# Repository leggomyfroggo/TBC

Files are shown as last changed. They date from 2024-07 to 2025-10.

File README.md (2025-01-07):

# TBC

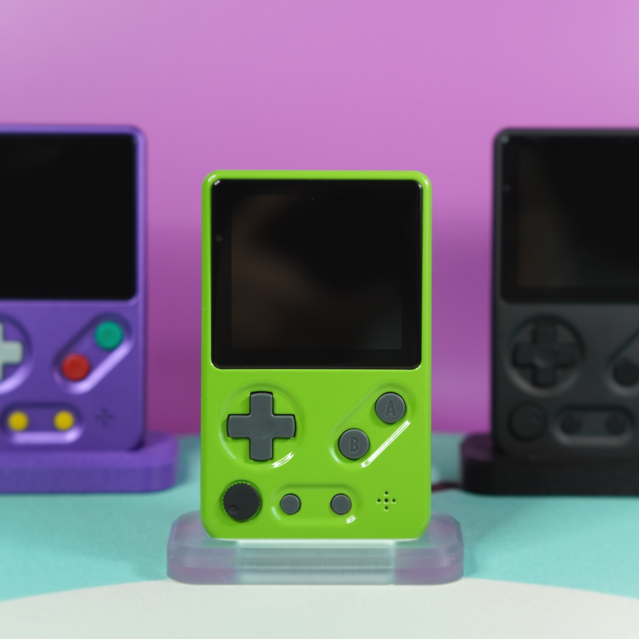
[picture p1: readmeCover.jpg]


The Tad Boy color is an answer to the question: how small can you make a Game Boy Color while still accepting original cartridges? That's it, that's all you get.

# Attribution
Before getting to the build, it's important to provide attribution to the other project(s) that have in part gone into the Tad Boy Color.
- **[Gekkio/gekkio-kicad-libs](https://github.com/Gekkio/gekkio-kicad-libs)**: The TBC incorporates several of Gekkio's excellent kicad symbols and footprints, including for the CPU, RAM(modified), link port, and cartridge connector. Huge thanks to Gekkio for making these available for others to use!
- Cody Wick for the incredible name suggestion, holy shit

# License
The Tad Boy Color and associated files are licensed under a CC BY-NC-ND 4.0 license. In short, this means:
- If you share the files, you must provide attribution.
- Commercial uses are not allowed without permission, i.e. production and sale of Tad Boy Colors or parts for profit is not allowed.
- You are free to modify these files for your own private use, but you are not allowed to distribute modified files.
Full license is linked at the bottom of this document.

# Disclaimer/Warning/For the love of God, read this
The Tad Boy is not an easy project, nor is it a professional product, and as such there are some things to keep in mind as you consider building one.

Assembly of the Tad Boy requires intermediate-advanced skills in soldering and electronics tinkering, including:
- Desoldering/soldering of large ICs
- Desoldering of through hole parts
- Soldering of small surface mount components, down to 0402
- Soldering of leadless ICs, for example the TPS61202
- Proficiency with a multimeter for troubleshooting and validation

This is in no way a project for beginners, and if you don't have experience with the above, I highly recommend starting smaller -- solder practice kits are cheap and easily available.

Along with needing the requisite skills, there is a very real possibility that you will irreparably damage either your donor Game Boy Color, or the resulting Tad Boy. Even the most skilled among us make mistakes, but it's important to keep in mind your own limits to avoid heartache and sorrow.

I am in no way a professional electrical engineer. All of my skills are self taught, or learned from other members of the modding community. While I have taken common sense measures to ensure that the Frog Boy is functional and safe, I can not guarantee that each and every decision made is correct. Build at your own discretion.

In summary, build at your own risk. I am not liable for any damage or injury caused by your insatiable need to build a Game Boy named after a baby amphibian.

# Navigating this Repo
- The files you will need to produce the Tad Boy Color parts are located in the `production_files` folder.
  - Files for each major piece are located in their own subfolders.
  - In general, production files are named according to the name of the part plus a 6 digit date code indicating the date of release.
    - PCB versions are the exception to this rule, and are labeled according to the board revision, e.g. X5, 01, 02, etc
  - Production files for old parts are located in those parts' respective `archive` folders.
  - The latest versions of each part will be guaranteed to work with one another. I only recommend downloading archived versions if you really know what you're doing.
- An interactive BOM is available in the `ibom` folder. iBOMs for different PCB revisions are in their own subfolders. Select the iBOM version that matches your PCB.

# Bill of Materials(BOM)
Below is the breakdown of all materials you will need to build a Tad Boy Color.

## Build Components
- **PCB:** The Tad Boy Color uses a fully custom PCB designed to fit within the custom shell while still using many of the original GBC components. The following board parameters are **required** or highly recommended, all other paremeters(color, etc) are up to you:
  - **Layers:** 4-layer
  - **Thickness:** 1mm
  - **Surface finish(recommended):** ENIG. HASL will probably be okay, but may not play well with the speaker contacts over time.
  - [**Order from PCBWay**](https://www.pcbway.com/project/shareproject/Tad_Boy_Color_876e4f73.html)
- **LCD Adapter Flex:** The shape of the board and LCD connector used on the main PCB requires the use of a custom flex cable to connect the TBC to the screen kit. The following parameters are **required**:
  - **Layers:** 2-layer
  - **Thickness:** 0.1mm or 0.11mm FFC
  - **Stiffener:** 0.2mm PI stiffener on edge connectors for total 0.3mm thickness. Have your chosen fab refer to the stiffener instructions on the "User Comments" layer
  - [**Order from PCBWay**](https://www.pcbway.com/project/shareproject/Tad_Boy_Color_LCD_Adapter_Flex_44b0462a.html)
- **Shell:** The shell for the Tad Boy Color is a fully custom design, designed specifically for CNC machining -- resin 3D printing should work, but is untested. Tested and verified materials are below, but all orders are at your own risk:
  - Verified CNC materials: Aluminum, polycarbonate, stainless steel
  - [**Order from PCBWay**](https://www.pcbway.com/project/shareproject/Tad_Boy_Color_876e4f73.html)
- **Volume Wheel:** The volume wheel is another custom piece, and is intended to be CNC machined. Resin printing will probably work, but is untested.
  - 081124 version can fit a 8mm(OD)x5mm(ID)x0.5mm PTFE coated nylon washer to reduce friction between wheel and shell.
  - [**Order from PCBWay**](https://www.pcbway.com/project/shareproject/Tad_Boy_Color_876e4f73.html)
- **Cartridge Shield:** Custom piece that fits behind the cartridge, allowing for a large enough opening in the metal shell to machine.
  - Verified 3D printing materials: FDM PLA, SLS nylon, MJF nylon
  - Verified CNC materials: Aluminum
  - [**Order from PCBWay**](https://www.pcbway.com/project/shareproject/Tad_Boy_Color_876e4f73.html)
- **Light pipe:** An optional light pipe can be added for the indicator LEDs to better diffuse them.
  - Verified 3D printing materials: FDM clear PLA, SLA clear resin
  - [**Order from PCBWay**](https://www.pcbway.com/project/shareproject/Tad_Boy_Color_876e4f73.html)
- **Screws:** The shell is designed to be put together using 7 x M2 3mm machine screws with flat tops. Options:
  - **450pcs M2 M2.5 M3 Screw Kit:** [From Amazon](https://www.amazon.com/gp/product/B07TDHZJLL/)
- **Buttons:** The Tad Boy Color uses buttons from the Game Boy Advance SP, either OEM or aftermarket. You will need a complete set, including the brightness button which is repurposed here as the power button. Some suggested buttons:
  - **FunnyPlaying:** [From RGRS](https://retrogamerepairshop.com/collections/gba-sp-buttons/products/funnyplaying-game-boy-advance-sp-buttons)
  - **RetroCNC(membrane version):** [From RGRS](https://retrogamerepairshop.com/collections/gba-sp-buttons/products/new-game-boy-sp-metal-buttons-by-retrocnc)
- **Membranes:** Similarly, the membranes used are also from the Game Boy Advance SP. Some suggested membranes:
  - **FunnyPlaying:** [From RGRS](https://retrogamerepairshop.com/collections/gba-sp-buttons/products/funnyplaying-game-boy-advance-sp-silicone-pads)
- **Screen:** This project is designed exclusively for the CGS 2.45" LCD kit for the Game Boy Color.
  - [Order from RGRS](https://retrogamerepairshop.com/collections/gbc-displays/products/game-boy-color-2-45-drop-in-backlight-lcd-kit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)
  - [Order from AliExpress](https://www.aliexpress.us/item/3256803777135552.html)
- **Screen Lens:** The Tad Boy color makes use of a custom designed glass screen lens. Suggested suppliers:
  - [**Order from FroggoCustoms**](https://froggocustoms.com/products/tad-boy-color-base-kit) - lens coming separately soon
  - Alibaba, requires obtaining quote with technical drawings
- **Battery:** The Tad Boy Color is designed to make use of aftermarket Joy Con batteries with minimal effort. The outer shroud/casing must be removed to fit properly. OEM batteries likely won't fit.

  NOTE: LiPo batteries can be dangerous if mishandled. NEVER use unprotected cells.

## Shell Ordering Notes
### CNC Machining
- When ordering the front shell, make sure you check the box indicating that you need tapped threads.
- For both front and back shells, be sure to include the technical drawings, and select 0.1mm as the tightest tolerance.

## PCB Components
- **Harvested GBC Parts:** You will need a donor GBC of revision CPU-05 or earlier -- CPU-06 revisions will NOT work -- that retains the following components in working order:
  - CPU
  - RAM
  - Link port(also available new: [AliExpress](https://www.aliexpress.us/item/3256803930669143.html))
- **New parts:** The full BOM for the Tad Boy Color be found in the repo, `bom.xlsx`. All non-Game Boy parts can be found in the shared Mouser cart below, and for that reason is the preferred vendor. Other parts can be obtained at the suggested links.
  - Non-Game Boy components(NOTE: These carts do not contain LEDs. Pick 3 x 0603 LEDs in whatever colors you want for the indicators):
    - [Mouser Shared Project](https://www.mouser.com/ProjectManager/ProjectDetail.aspx?AccessID=6273a53e17)
    - [DigiKey Shared Project](https://www.digikey.com/en/mylists/list/A9QP98UG8B) - NOTE: DigiKey does not stock the crystal or volume potentiometer. Order from Mouser if you can.
  - Game Boy Advance SP cartridge slot: [AliExpress](https://www.aliexpress.us/item/3256802533466823.html)
 
# Recommended Assembly Procedure
At this point, if you feel confident in your skills you can proceed with the complete build from PCB to final unit -- assembly after building the PCB is relatively straightforward.

However, I've devised an assembly strategy after assembling a few units that will allow you to check your work along the way, and I highly recommend that you follow along.

Unless otherwise noted, you should install all highlighted parts in a given step, and then proceed to the corresponding "Testing" section.

## PCB Assembly
### 1. Tactile switches
While this step can be done at any point of your choosing, I recommend doing it first for two reasons:
1. When using a hot plate to install the tactile switches, it's much easier to do so when the PCB is otherwise empty, and
2. Installing them early lets you better test in later stages.

| Front Parts | Back Parts |
| --- | --- |
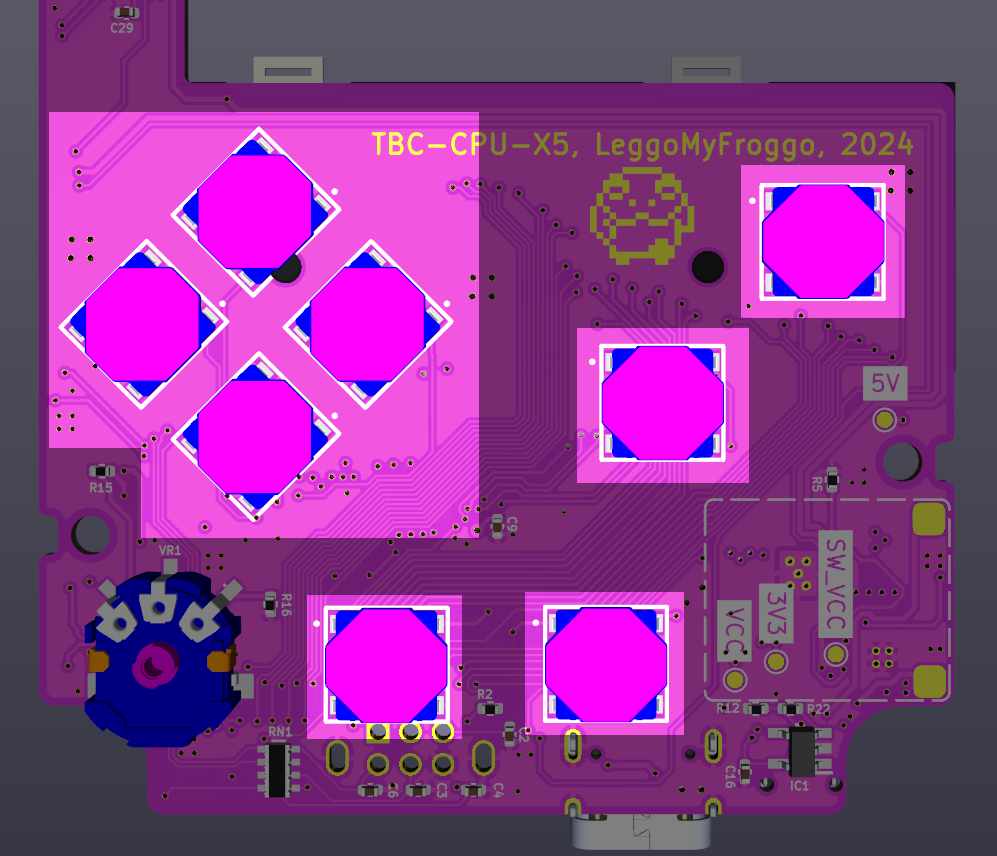
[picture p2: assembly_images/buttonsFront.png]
|  | N/A  |

### 2. Power
| Front Parts | Back Parts |
| --- | --- |
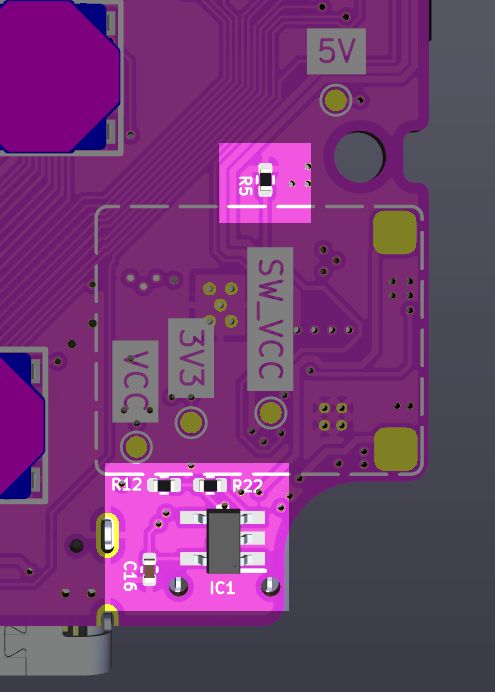
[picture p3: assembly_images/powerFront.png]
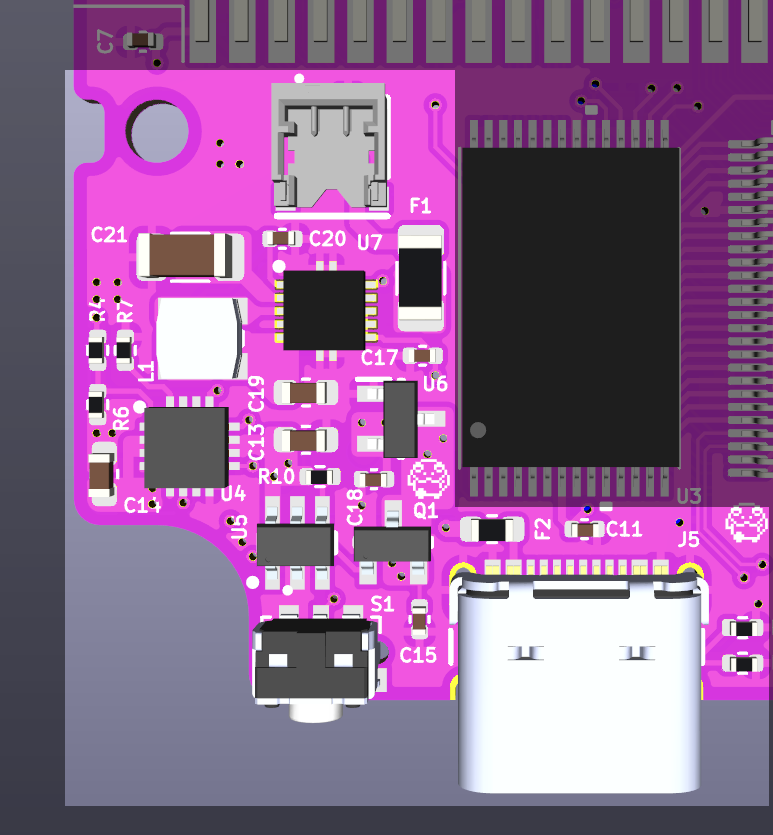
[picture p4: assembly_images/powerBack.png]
|  |  |

#### Testing:
To set up for testing, plug the battery into the battery connector below the cartridge slot. With your multimeter in DC voltage mode, verify test point voltages against these values in both on and off states for the system -- the system will be off initially. Tap the power button to toggle it on and off.
| Test Point | Off  | On  |
| --- | ---- | --- |
| SW_VCC | BAT+ | BAT+ |
| VCC | ~0V  | BAT+ |
| 5V | ~0V  | 5V |
| 3V3 | ~0V  | 3.3V |

NOTE: The VCC, 5V, and 3V3 rails may retain some voltage following system power down, but they should trend down to 0V over time.

### 3. The brains of the operation
| Front Parts | Back Parts |
| --- | --- |
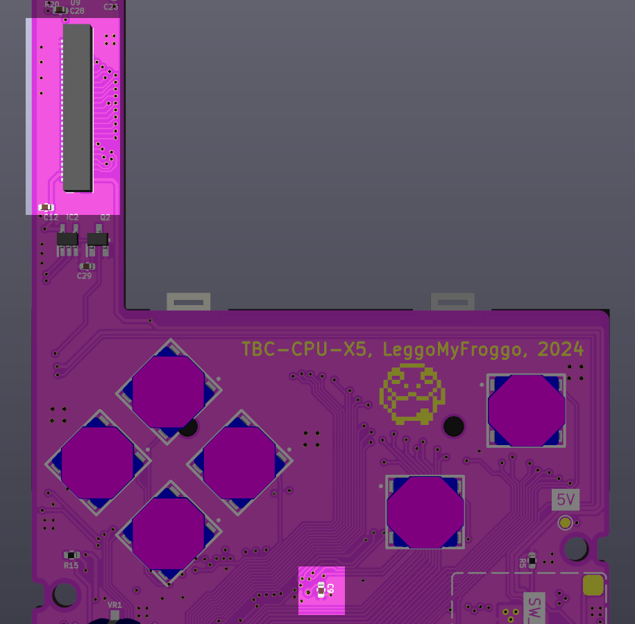
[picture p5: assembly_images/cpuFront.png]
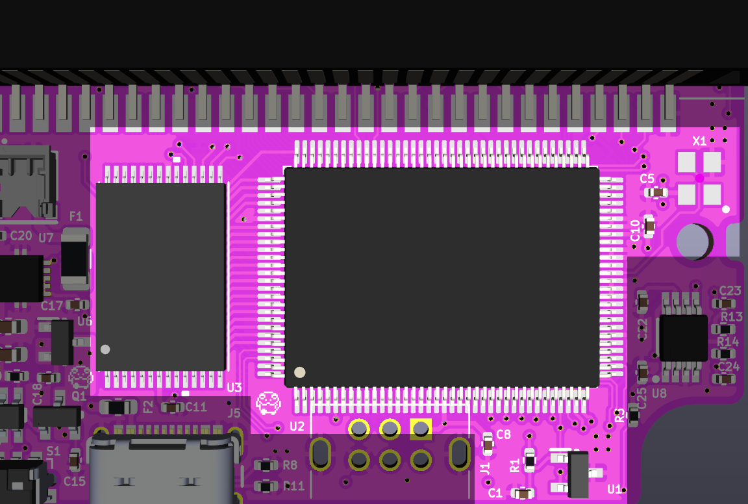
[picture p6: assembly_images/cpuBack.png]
|  |  |

#### Testing:
1. Plug the larger end of the screen adapter flex cable into the screen driver board. Connector is bottom contact, meaning the gold fingers should face toward the surface of the PCB.
2. Plug the other end into the LCD connector on the motherboard. Connector is bottom contact, meaning the gold fingers should face toward the surface of the PCB.
3. Plug in the battery as in step 2.
4. Turn the system on by pressing the power button.
5. If all is well, you will see the familiar GBC boot screen appear. If the colors look funky, it's likely that not all CPU or RAM pins have been sufficiently joined to their pads. I highly recommend fixing this before installing the cart slot and link port as they will make access much harder.
6. Turn off the system and unplug the battery.

### 4. Cart slot
| Front Parts | Back Parts |
| --- | --- |
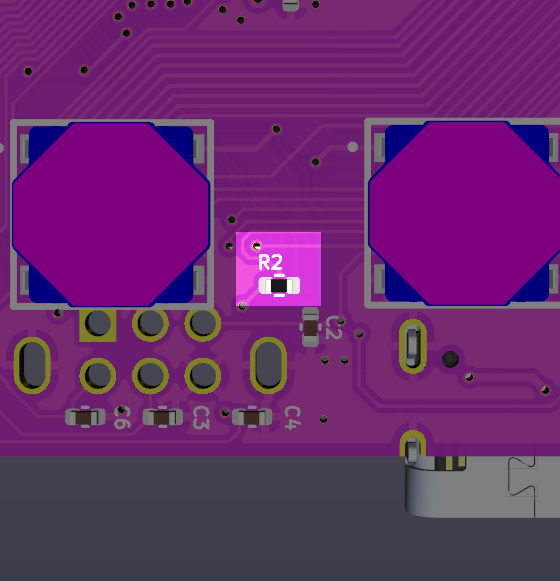
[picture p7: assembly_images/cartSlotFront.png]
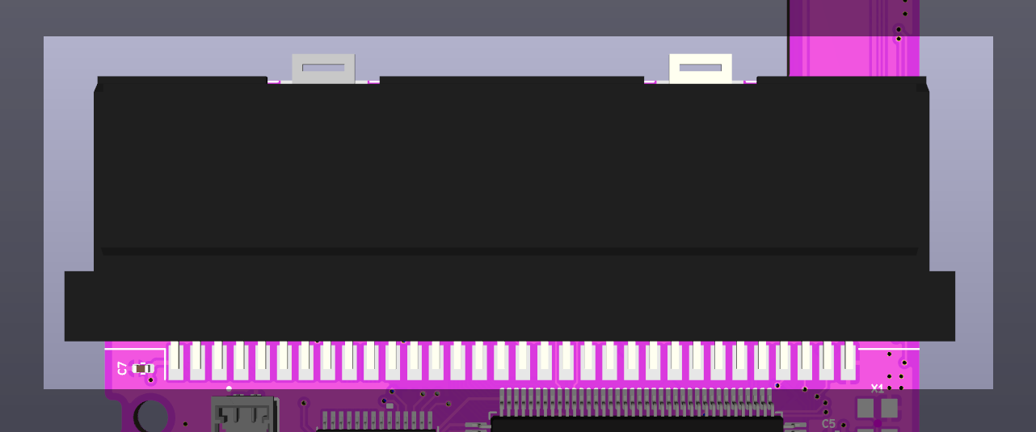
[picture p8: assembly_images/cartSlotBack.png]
|  |  |

#### Testing:
1. Plug in the battery as in step 2.
2. Insert a cartridge into the cart slot.
3. Turn the system on by pressing the power button.
4. If all is well, the cartridge will boot and play correctly.
5. Turn off the system and unplug the battery.

### 5. Audio
| Front Parts | Back Parts |
| --- | --- |
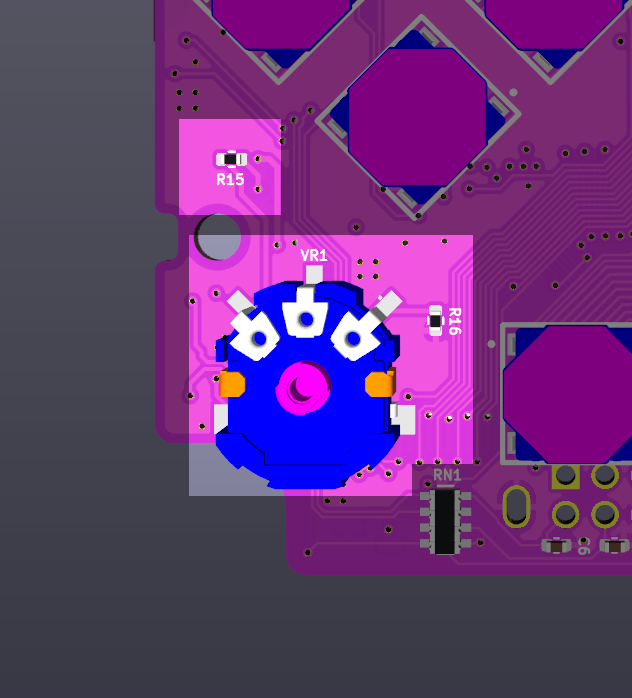
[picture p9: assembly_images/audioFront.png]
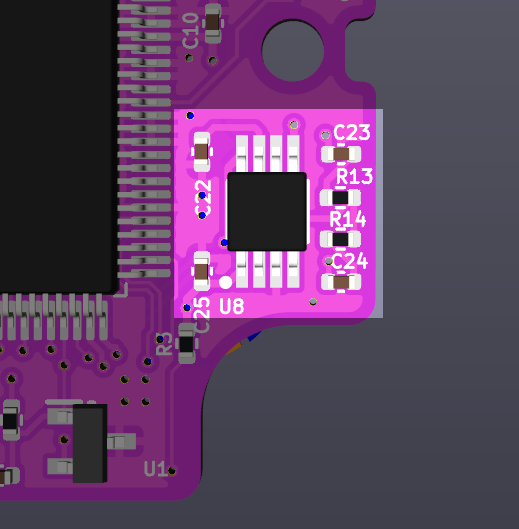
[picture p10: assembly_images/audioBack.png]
|  |  |

#### Testing:
1. Plug in the battery as in step 2.
2. Hold the contacts of the speaker to the corresponding pads on the motherboard.
3. Turn the system on by pressing the power button.
4. You should hear the start up "ding" if audio is working. If not, make sure the volume is turned up.
5. Turn off the system and unplug the battery.

### 6. Screen brightness control
| Front Parts | Back Parts |
| --- | --- |
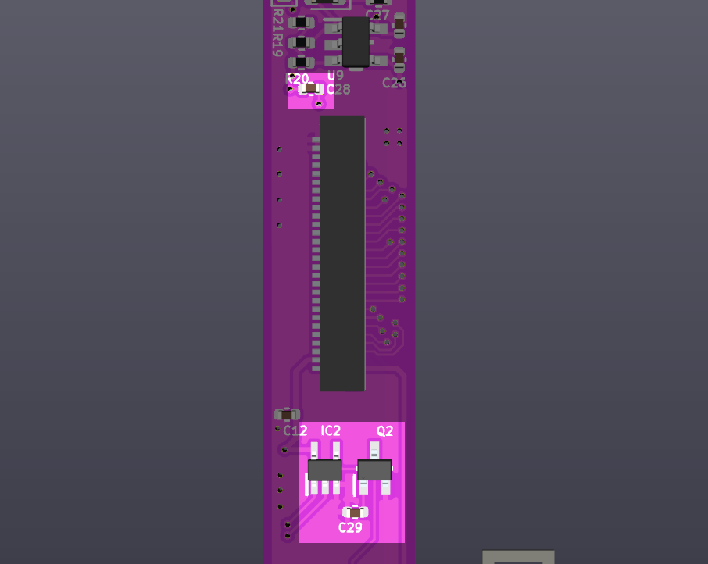
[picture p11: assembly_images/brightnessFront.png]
|  | N/A |

#### Testing:
1. Plug in the battery as in step 2.
2. Turn the system on by pressing the power button.
3. Press down + select at the same time and verify that the brightness level changes.
4. Long press down + select and verify that the pixel mode changes.
5. Turn off the system and unplug the battery.

### 7. Indicator LEDs
| Front Parts | Back Parts |
| --- | --- |
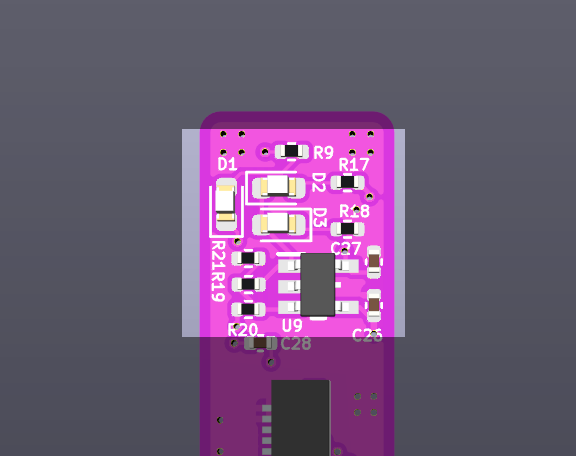
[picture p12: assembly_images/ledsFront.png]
|  | N/A |

#### Testing:
1. Plug in the battery as in step 2.
2. Turn the system on by pressing the power button.
3. If the battery voltage is above 3.5V, D2 should illuminate. If it is below, D3 will illuminate.
4. Plug in a USB-C cable. D1 should illuminate to indicate that the battery is charging.
5. Turn off the system and unplug the battery.

### 8. EXT port
| Front Parts | Back Parts |
| --- | --- |
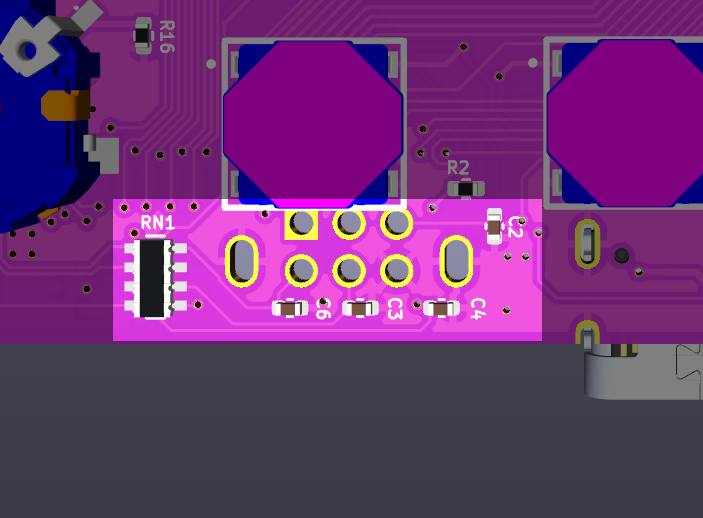
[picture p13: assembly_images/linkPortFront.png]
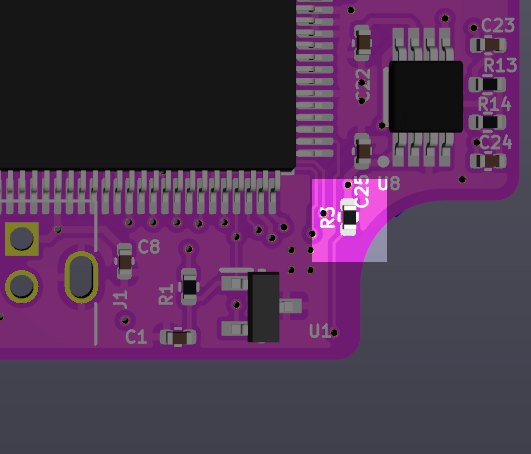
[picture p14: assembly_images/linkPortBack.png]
|  |  |

#### Testing:
1. Plug in the battery as in step 2.
2. Turn the system on by pressing the power button.
3. Connect a link cable from the EXT port to the EXT port of a known working Game Boy and verify functionality with a game of your choosing.
4. Turn off the system and unplug the battery.

<p xmlns:cc="http://creativecommons.org/ns#" xmlns:dct="http://purl.org/dc/terms/"><a property="dct:title" rel="cc:attributionURL" href="https://github.com/leggomyfroggo/TBC/">Tad Boy Color</a> by <a rel="cc:attributionURL dct:creator" property="cc:attributionName" href="https://github.com/leggomyfroggo">Chris Hackmann</a> is licensed under <a href="https://creativecommons.org/licenses/by-nc-nd/4.0/?ref=chooser-v1" target="_blank" rel="license noopener noreferrer" style="display:inline-block;">CC BY-NC-ND 4.0</a></p>

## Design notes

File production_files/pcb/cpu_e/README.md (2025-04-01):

# Overview
These are the gerbers and iBOM for a CPU E version of the Tad Boy Color PCB, adapted by Natalie the Nerd. Compatible with the rest of the TBC components.

Natalie has built and tested this board herself to ensure functionality. Nonetheless, consider this experimental, and **not supported by either of us**.

Give Natalie your monies because she's awesome: [Natalie the Nerd on ko-fi](https://ko-fi.com/nataliethenerd).

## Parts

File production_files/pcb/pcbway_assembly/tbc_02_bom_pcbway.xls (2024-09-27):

designator | quantity | value | pack | mpn | mount_type | notes
C1, C16, C17, C20, C26 | 5 | 1uF, 25V | C_0402_1005Metric |  | smt
C10, C11, C12, C15, C27, C29, C5, C7, C8, C9 | 10 | 100nF, 16V | C_0402_1005Metric |  | smt
C13, C14 | 2 | 4.7uF, 16V | C_0603_1608Metric |  | smt
C18, C22, C25 | 3 | 2.2uF, 16V | C_0402_1005Metric |  | smt
C19 | 1 | 10uF, 16V | C_0603_1608Metric |  | smt
C2, C28, C30 | 3 | 22pF, 50V | C_0402_1005Metric |  | smt
C21 | 1 | 22uF, 10V | C_1206_3216Metric |  | smt
C23, C24 | 2 | 0.22uF, 16V | C_0402_1005Metric |  | smt
C3, C4, C6 | 3 | 100pF, 50V | C_0402_1005Metric |  | smt
D1 | 1 | YELLOW LED | LED_0603_1608Metric |  | smt
D2 | 1 | GREEN LED | LED_0603_1608Metric |  | smt
D3 | 1 | RED LED | LED_0603_1608Metric |  | smt
F1 | 1 | 2.5A | Fuse_1206_3216Metric |  | smt
F2 | 1 | 1A | Fuse_0603_1608Metric |  | smt
IC1 | 1 | MCP1319MT-33AE_OT | SOT95P270X145-5N | MCP1319MT-33AE_OT | smt
IC2 | 1 | 74AHCT1G02DCKRG4 | SOT65P210X110-5N | 74AHCT1G02DCKRG4 | smt
J3 | 1 | 28P bottom | FH3328S05SH10 | FH3328S05SH10 | smt
J4 | 1 | 78171-0002 | 78171-0002 | 78171-0002 | smt
J5 | 1 | USB4105-GF-A | GCT_USB4105-GF-A | USB4105-GF-A | smt
L1 | 1 | 2.2uH | VLS3012 |  | smt
Q1 | 1 | DMP6350SQ-7 | SOT96P240X110-3N | DMP6350SQ-7 | smt
Q2 | 1 | NTS4409NT1G | SOT65P220X100-3N | NTS4409NT1G | smt
R1, R10, R22 | 3 | 10K, 1% | R_0402_1005Metric |  | smt
R11 | 1 | 5.1K ,1% | R_0402_1005Metric |  | smt
R12 | 1 | 100K, 1% | R_0402_1005Metric |  | smt
R13, R14, R2 | 3 | 100, 1% | R_0402_1005Metric |  | smt
R15 | 1 | 15K, 1% | R_0402_1005Metric |  | smt
R16, R8 | 2 | 5.1K, 1% | R_0402_1005Metric |  | smt
R17, R3 | 2 | 5.6K, 1% | R_0402_1005Metric |  | smt
R18, R7 | 2 | 3.3K, 1% | R_0402_1005Metric |  | smt
R19 | 1 | 430K, 0.5% | R_0402_1005Metric |  | smt
R20 | 1 | 20K, 0.5% | R_0402_1005Metric |  | smt
R21 | 1 | 47K, 0.5% | R_0402_1005Metric |  | smt
R4 | 1 | 200K, 1% | R_0402_1005Metric |  | smt
R5, R9 | 2 | 1K, 1% | R_0402_1005Metric |  | smt
R6 | 1 | 49.9K, 1% | R_0402_1005Metric |  | smt
RN1 | 1 | 270, 1% | R_Array_Concave_4x0603 |  | smt
S1 | 1 | SKRTLAE010 | SW_SKRTLAE010 | SKRTLAE010 | smt
SW1, SW2, SW3, SW4, SW5, SW6, SW7, SW8 | 8 | SKRRAAE010 | SW_SKRRAAE010 | SKRRAAE010 | smt
U1 | 1 | TLV803EB33VDBZR | SOT95P237X112-3N | TLV803EB33VDBZR | smt
U4 | 1 | BQ24072TRGTR | QFN50P300X300X100-17N-D | BQ24072TRGTR | smt
U5 | 1 | MAX16054AZT+T | SOT95P275X110-6N | MAX16054AZT+T | smt
U6 | 1 | MCP1799T-3302H_TT | SOT95P237X112-3N | MCP1799T-3302H_TT | smt
U7 | 1 | TPS61202DSC | Texas_DSC0010J_ThermalVias | TPS61202DSC | smt
U8 | 1 | LM4875MM_NOPB | SOP65P490X110-8N | LM4875MM_NOPB | smt
U9 | 1 | TLV3201AIDBVR | SOT95P280X145-5N | TLV3201AIDBVR | smt
VR1 | 1 | 10K | RK08H113003Q | RK08H113003Q | tht
X1 | 1 | 8.388MHz | Oscillator_SMD_Abracon_ASE-4Pin_3.2x2.5mm | SG-8018CG 8.388608M-TJHPA0 | smt | Available from Mouser

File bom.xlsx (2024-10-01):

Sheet: 02
Tad Boy Color BOM for board revisions 02, Revised 9/30/2024
Designator(s) | Quantity | Value/Part Number | Package | Notes | URL | Part# | Mouser? | DigiKey?
C14,C13 | 2 | 4.7uF | 0603 |  | https://www.mouser.com/ProductDetail/81-GRM188Z71A475ME5D | 81-GRM188Z71A475ME5D | Y
C19 | 1 | 10uF | 0603 |  | https://www.mouser.com/ProductDetail/81-GRM188Z71A106KA3D | 81-GRM188Z71A106KA3D | Y
C2,C28,C30 | 2 | 22pF | 0402 |  | https://www.mouser.com/ProductDetail/80-C0402C220G3HACTU | 80-C0402C220G3HACTU | Y
C20,C17,C1,C26,C16 | 5 | 1uF | 0402 |  | https://www.mouser.com/ProductDetail/81-GRM155R61E105MA2D | 81-GRM155R61E105MA2D | Y
C21 | 1 | 22uF | 1206 |  | https://www.mouser.com/ProductDetail/581-1206ZC226MAT2A | 581-1206ZC226MAT2A | Y
C22,C25,C18 | 3 | 2.2uF | 0402 |  | https://www.mouser.com/ProductDetail/81-GRM155R61E225ME1D | 81-GRM155R61E225ME1D | Y
C23,C24 | 2 | 0.22uF | 0402 |  | https://www.mouser.com/ProductDetail/581-0402YC224KAT2A | 581-0402YC224KAT2A | Y
C6,C3,C4 | 3 | 100pF | 0402 |  | https://www.mouser.com/ProductDetail/77-VJ0402Y101MXAPBC | 77-VJ0402Y101MXAPBC | Y
C7,C11,C15,C5,C10,C8,C12,C27,C29,C9 | 10 | 100nF | 0402 |  | https://www.mouser.com/ProductDetail/80-C0402C104M4R | 80-C0402C104M4R | Y
D3,D2,D1 | 3 | LED | 0603
F1 | 1 | 2.5A | 1206 |  | https://www.mouser.com/ProductDetail/667-ERB-RG2R50V | 667-ERB-RG2R50V | Y
F2 | 1 | 1A | 0603 |  | https://www.mouser.com/ProductDetail/594-MFU0603FF01000P1 | 594-MFU0603FF01000P1 | Y
IC1 | 1 | MCP1319MT-33AE_OT | SOT-23-5 |  | https://www.mouser.com/ProductDetail/579-MCP1319MT33AE-OT | 579-MCP1319MT33AE-OT | Y
IC2 | 1 | 74AHCT1G02DCKRG4 | SOT65P210X110-5N |  | https://www.mouser.com/ProductDetail/595-74AHCT1G02DCKRG4 | 595-74AHCT1G02DCKRG4 | Y
J1 | 1 | Link port | -
J2 | 1 | Cartridge slot | -
J3 | 1 | FH33-28S-0.5SH_10_ | FH3328S05SH10 |  | https://www.mouser.com/ProductDetail/798-FH3328S0.5SH10 | 798-FH3328S0.5SH10 | Y
J4 | 1 | 78171-0002 | 78171-0002 |  | https://www.mouser.com/ProductDetail/538-78171-0002 | 538-78171-0002 | Y
J5 | 1 | USB4105-GF-A | GCT_USB4105-GF-A |  | https://www.mouser.com/ProductDetail/640-USB4105-GF-A | 640-USB4105-GF-A | Y
L1 | 1 | VLS3012HBX-2R2M-N | VLS3012 |  | https://www.mouser.com/ProductDetail/810-VLS3012HBX2R2M-N | 810-VLS3012HBX2R2M-N | Y
Q1 | 1 | DMP6350SQ-7 | SOT-23 |  | https://www.mouser.com/ProductDetail/621-DMP6350SQ-7 | 621-DMP6350SQ-7 | Y
Q2 | 1 | NTS4409NT1G | SOT65P220X100-3N |  | https://www.mouser.com/ProductDetail/863-NTS4409NT1G | 863-NTS4409NT1G | Y
R1,R10,R22 | 3 | 10K | 0402 |  | https://www.mouser.com/ProductDetail/652-CR0402FX-1002GLF | 652-CR0402FX-1002GLF | Y
R12 | 1 | 100K | 0402 |  | https://www.mouser.com/ProductDetail/667-ERJ-U02J104X | 667-ERJ-U02J104X | Y
R14,R13,R2 | 3 | 100 | 0402 |  | https://www.mouser.com/ProductDetail/652-CR0402AJW-101GLF | 652-CR0402AJW-101GLF | Y
R15 | 1 | 15K | 0402 |  | https://www.mouser.com/ProductDetail/652-CR0402FX-1502GLF | 652-CR0402FX-1502GLF | Y
R18 | 1 | 3.3K | 0402 |  | https://www.mouser.com/ProductDetail/652-CR0402FX-3301GLF | 652-CR0402FX-3301GLF | Y
R19 | 1 | 430K | 0402 |  | https://www.mouser.com/ProductDetail/71-CRCW0402430KFKEDC | 71-CRCW0402430KFKEDC | Y
R20 | 1 | 20K | 0402 |  | https://www.mouser.com/ProductDetail/652-CR0402FX-2002GLF | 652-CR0402FX-2002GLF | Y
R21 | 1 | 47K | 0402 |  | https://www.mouser.com/ProductDetail/652-CR0402FX-4702GLF | 652-CR0402FX-4702GLF | Y
R3,R17 | 2 | 5.6K | 0402 |  | https://www.mouser.com/ProductDetail/652-CR0402JW-562GLF | 652-CR0402JW-562GLF | Y
R4 | 1 | 200K | 0402 |  | https://www.mouser.com/ProductDetail/652-CR0402-JW-204GLF | 652-CR0402-JW-204GLF | Y
R5,R9 | 2 | 1K | 0402 |  | https://www.mouser.com/ProductDetail/71-CRCW0402-1.0K-E3 | 71-CRCW0402-1.0K-E3 | Y
R6 | 1 | 49.9K | 0402 |  | https://www.mouser.com/ProductDetail/603-RP0402BRD0749K9L | 603-RP0402BRD0749K9L | Y
R7,R8,R11,R16 | 4 | 5.1K | 0402 |  | https://www.mouser.com/ProductDetail/652-CR0402-JW-512GLF | 652-CR0402-JW-512GLF | Y
RN1 | 1 | 270x4 | 1206 |  | https://www.mouser.com/ProductDetail/603-TC164-JR-07270RL | 603-TC164-JR-07270RL | Y
S1 | 1 | SKRTLAE010 | SW_SKRTLAE010 |  | https://www.mouser.com/ProductDetail/688-SKRTLA | 688-SKRTLA | Y
SW6,SW4,SW8,SW7,SW5,SW2,SW3,SW1 | 8 | SKRRAAE010 | - |  | https://www.mouser.com/ProductDetail/688-SKRRAA | 688-SKRRAA | Y
U1 | 1 | TLV803EB33VDBZR | SOT-23 |  | https://www.mouser.com/ProductDetail/595-TLV803EB33VDBZR | 595-TLV803EB33VDBZR | Y
U2 | 1 | CGB CPU | -
U3 | 1 | CGB RAM | -
U4 | 1 | BQ24072TRGTR | VQFN-16 |  | https://www.mouser.com/ProductDetail/595-BQ24072TRGTR | 595-BQ24072TRGTR | Y
U5 | 1 | MAX16054AZT+T | SOT-23-6 |  | https://www.mouser.com/ProductDetail/700-MAX16054AZTT | 700-MAX16054AZTT | Y
U6 | 1 | MCP1799T-3302H_TT | SOT-23 |  | https://www.mouser.com/ProductDetail/Microchip-Technology/MCP1799T-3302H-TT | MCP1799T-3302H-TT | Y
U7 | 1 | TPS61202DSC | WSON-10 |  | https://www.mouser.com/ProductDetail/595-TPS61202DSCR | 595-TPS61202DSCR | Y
U8 | 1 | LM4875MM_NOPB | VSSOP-8 |  | https://www.mouser.com/ProductDetail/926-LM4875MM-NOPB | 926-LM4875MM-NOPB | Y
U9 | 1 | TLV3201AIDBVR | SOT-23-5 |  | https://www.mouser.com/ProductDetail/595-TLV3201AIDBVR | 595-TLV3201AIDBVR | Y
VR1 | 1 | RK08H113003Q | RK08H113003Q |  | https://www.mouser.com/ProductDetail/688-RK08H113003Q | 688-RK08H113003Q | Y
X1 | 1 | 732-CG838868MTJHPA | - |  | https://www.mouser.com/ProductDetail/732-CG838868MTJHPA | 732-CG838868MTJHPA | Y
Battery | 1 | Joy Con battery | - |  | https://www.ifixit.com/products/nintendo-switch-joy-con-controller-replacement-battery?variant=39372012322919 |  | N
Speaker | 1 | CMS-151135-18S-X8 | - |  | https://www.mouser.com/ProductDetail/CUI-Devices/CMS-151135-18S-X8?qs=9vOqFld9vZXAip8uBsd1PA%3D%3D |  | Y

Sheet: x4x501
Tad Boy Color BOM for board revisions X4, X5, and 01, Revised 7/11/2024
Designator(s) | Quantity | Value/Part Number | Package | Notes | URL | Part# | Mouser? | DigiKey?
C14,C13 | 2 | 4.7uF | 0603 |  | https://www.mouser.com/ProductDetail/81-GRM188Z71A475ME5D | 81-GRM188Z71A475ME5D | Y
C19 | 1 | 10uF | 0603 |  | https://www.mouser.com/ProductDetail/81-GRM188Z71A106KA3D | 81-GRM188Z71A106KA3D | Y
C2,C28 | 2 | 22pF | 0402 |  | https://www.mouser.com/ProductDetail/80-C0402C220G3HACTU | 80-C0402C220G3HACTU | Y
C20,C17,C1,C26,C16 | 5 | 1uF | 0402 |  | https://www.mouser.com/ProductDetail/81-GRM155R61E105MA2D | 81-GRM155R61E105MA2D | Y
C21 | 1 | 22uF | 1206 |  | https://www.mouser.com/ProductDetail/581-1206ZC226MAT2A | 581-1206ZC226MAT2A | Y
C22,C25,C18 | 3 | 2.2uF | 0402 |  | https://www.mouser.com/ProductDetail/81-GRM155R61E225ME1D | 81-GRM155R61E225ME1D | Y
C23,C24 | 2 | 0.22uF | 0402 |  | https://www.mouser.com/ProductDetail/581-0402YC224KAT2A | 581-0402YC224KAT2A | Y
C6,C3,C4 | 3 | 100pF | 0402 |  | https://www.mouser.com/ProductDetail/77-VJ0402Y101MXAPBC | 77-VJ0402Y101MXAPBC | Y
C7,C11,C15,C5,C10,C8,C12,C27,C29,C9 | 10 | 100nF | 0402 |  | https://www.mouser.com/ProductDetail/80-C0402C104M4R | 80-C0402C104M4R | Y
D3,D2,D1 | 3 | LED | 0603
F1 | 1 | 2.5A | 1206 |  | https://www.mouser.com/ProductDetail/667-ERB-RG2R50V | 667-ERB-RG2R50V | Y
F2 | 1 | 1A | 0603 |  | https://www.mouser.com/ProductDetail/594-MFU0603FF01000P1 | 594-MFU0603FF01000P1 | Y
IC1 | 1 | MCP1319MT-33AE_OT | SOT-23-5 |  | https://www.mouser.com/ProductDetail/579-MCP1319MT33AE-OT | 579-MCP1319MT33AE-OT | Y
IC2 | 1 | 74AHCT1G02DCKRG4 | SOT65P210X110-5N |  | https://www.mouser.com/ProductDetail/595-74AHCT1G02DCKRG4 | 595-74AHCT1G02DCKRG4 | Y
J1 | 1 | Link port | -
J2 | 1 | Cartridge slot | -
J3 | 1 | FH33-28S-0.5SH_10_ | FH3328S05SH10 |  | https://www.mouser.com/ProductDetail/798-FH3328S0.5SH10 | 798-FH3328S0.5SH10 | Y
J4 | 1 | 78171-0002 | 78171-0002 |  | https://www.mouser.com/ProductDetail/538-78171-0002 | 538-78171-0002 | Y
J5 | 1 | USB4105-GF-A | GCT_USB4105-GF-A |  | https://www.mouser.com/ProductDetail/640-USB4105-GF-A | 640-USB4105-GF-A | Y
L1 | 1 | VLS3012HBX-2R2M-N | VLS3012 |  | https://www.mouser.com/ProductDetail/810-VLS3012HBX2R2M-N | 810-VLS3012HBX2R2M-N | Y
Q1 | 1 | DMP6350SQ-7 | SOT-23 |  | https://www.mouser.com/ProductDetail/621-DMP6350SQ-7 | 621-DMP6350SQ-7 | Y
Q2 | 1 | NTS4409NT1G | SOT65P220X100-3N |  | https://www.mouser.com/ProductDetail/863-NTS4409NT1G | 863-NTS4409NT1G | Y
R1,R10,R22 | 3 | 10K | 0402 |  | https://www.mouser.com/ProductDetail/652-CR0402FX-1002GLF | 652-CR0402FX-1002GLF | Y
R12 | 1 | 100K | 0402 |  | https://www.mouser.com/ProductDetail/667-ERJ-U02J104X | 667-ERJ-U02J104X | Y
R14,R13,R2 | 3 | 100 | 0402 |  | https://www.mouser.com/ProductDetail/652-CR0402AJW-101GLF | 652-CR0402AJW-101GLF | Y
R15 | 1 | 15K | 0402 |  | https://www.mouser.com/ProductDetail/652-CR0402FX-1502GLF | 652-CR0402FX-1502GLF | Y
R18 | 1 | 3.3K | 0402 |  | https://www.mouser.com/ProductDetail/652-CR0402FX-3301GLF | 652-CR0402FX-3301GLF | Y
R19 | 1 | 430K | 0402 |  | https://www.mouser.com/ProductDetail/71-CRCW0402430KFKEDC | 71-CRCW0402430KFKEDC | Y
R20 | 1 | 20K | 0402 |  | https://www.mouser.com/ProductDetail/652-CR0402FX-2002GLF | 652-CR0402FX-2002GLF | Y
R21 | 1 | 47K | 0402 |  | https://www.mouser.com/ProductDetail/652-CR0402FX-4702GLF | 652-CR0402FX-4702GLF | Y
R3,R17 | 2 | 5.6K | 0402 |  | https://www.mouser.com/ProductDetail/652-CR0402JW-562GLF | 652-CR0402JW-562GLF | Y
R4 | 1 | 200K | 0402 |  | https://www.mouser.com/ProductDetail/652-CR0402-JW-204GLF | 652-CR0402-JW-204GLF | Y
R5,R9 | 2 | 1K | 0402 |  | https://www.mouser.com/ProductDetail/71-CRCW0402-1.0K-E3 | 71-CRCW0402-1.0K-E3 | Y
R6 | 1 | 49.9K | 0402 |  | https://www.mouser.com/ProductDetail/603-RP0402BRD0749K9L | 603-RP0402BRD0749K9L | Y
R7,R8,R11,R16 | 4 | 5.1K | 0402 |  | https://www.mouser.com/ProductDetail/652-CR0402-JW-512GLF | 652-CR0402-JW-512GLF | Y
RN1 | 1 | 270x4 | 1206 |  | https://www.mouser.com/ProductDetail/603-TC164-JR-07270RL | 603-TC164-JR-07270RL | Y
S1 | 1 | SKRTLAE010 | SW_SKRTLAE010 |  | https://www.mouser.com/ProductDetail/688-SKRTLA | 688-SKRTLA | Y
SW6,SW4,SW8,SW7,SW5,SW2,SW3,SW1 | 8 | SKRRAAE010 | - |  | https://www.mouser.com/ProductDetail/688-SKRRAA | 688-SKRRAA | Y
U1 | 1 | TLV803EB33VDBZR | SOT-23 |  | https://www.mouser.com/ProductDetail/595-TLV803EB33VDBZR | 595-TLV803EB33VDBZR | Y
U2 | 1 | CGB CPU | -
U3 | 1 | CGB RAM | -
U4 | 1 | BQ24072TRGTR | VQFN-16 |  | https://www.mouser.com/ProductDetail/595-BQ24072TRGTR | 595-BQ24072TRGTR | Y
U5 | 1 | MAX16054AZT+T | SOT-23-6 |  | https://www.mouser.com/ProductDetail/700-MAX16054AZTT | 700-MAX16054AZTT | Y
U6 | 1 | MCP1799T-3302H_TT | SOT-23 |  | https://www.mouser.com/ProductDetail/Microchip-Technology/MCP1799T-3302H-TT | MCP1799T-3302H-TT | Y
U7 | 1 | TPS61202DSC | WSON-10 |  | https://www.mouser.com/ProductDetail/595-TPS61202DSCR | 595-TPS61202DSCR | Y
U8 | 1 | LM4875MM_NOPB | VSSOP-8 |  | https://www.mouser.com/ProductDetail/926-LM4875MM-NOPB | 926-LM4875MM-NOPB | Y
U9 | 1 | TLV3201AIDBVR | SOT-23-5 |  | https://www.mouser.com/ProductDetail/595-TLV3201AIDBVR | 595-TLV3201AIDBVR | Y
VR1 | 1 | RK08H113003Q | RK08H113003Q |  | https://www.mouser.com/ProductDetail/688-RK08H113003Q | 688-RK08H113003Q | Y
X1 | 1 | 732-CG838868MTJHPA | - |  | https://www.mouser.com/ProductDetail/732-CG838868MTJHPA | 732-CG838868MTJHPA | Y
Battery | 1 | Joy Con battery | - |  | https://www.ifixit.com/products/nintendo-switch-joy-con-controller-replacement-battery?variant=39372012322919 |  | N
Speaker | 1 | CMS-151135-18S-X8 | - |  | https://www.mouser.com/ProductDetail/CUI-Devices/CMS-151135-18S-X8?qs=9vOqFld9vZXAip8uBsd1PA%3D%3D |  | Y

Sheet: PartsDB
Value | Package | URL
- | 802040 | https://www.aliexpress.us/item/3256802244810488.html
4.7uF | 0603 | https://www.mouser.com/ProductDetail/81-GRM188Z71A475ME5D
10uF | 0603 | https://www.mouser.com/ProductDetail/81-GRM188Z71A106KA3D
22uF | 1206 | https://www.mouser.com/ProductDetail/581-1206ZC226MAT2A
1uF | 0603 | https://www.mouser.com/ProductDetail/581-0603YC105KAT2A
100uF | 1206 | https://www.mouser.com/ProductDetail/581-TLJA107M10R1400
18pF | 0603 | https://www.mouser.com/ProductDetail/581-06035A180J
0.22uF | 0603 | https://www.mouser.com/ProductDetail/603-AC0603X7R9BB224
22pF | 0603 | https://www.mouser.com/ProductDetail/581-06035C220JAT2A
100pF | 0603 | https://www.mouser.com/ProductDetail/581-0603YC101KAT2A
27pF | 0603 | https://www.mouser.com/ProductDetail/581-06035A270J
100nF | 0603 | https://www.mouser.com/ProductDetail/581-06035C104KAT2A
LED | 0603
2.5A | 1206 | https://www.mouser.com/ProductDetail/667-ERB-RG2R50V
1A | 0603 | https://www.mouser.com/ProductDetail/594-MFU0603FF01000P1
FBx4 | 1206 | https://www.mouser.com/ProductDetail/81-BLA3216A601SG4
Link port | -
Cartridge slot | -
62684-502100ALF | 62684-502100ALF | https://www.mouser.com/ProductDetail/649-62684-502100ALF
JST PH 2-pin | -
USB4105-GF-A | GCT_USB4105-GF-A | https://www.mouser.com/ProductDetail/640-USB4105-GF-A
SJ2-3593D-SMT-TR | SJ23593DSMTTR | https://www.mouser.com/ProductDetail/490-SJ2-3593D-SMT-TR
VLS3012HBX-2R2M-N | VLS3012 | https://www.mouser.com/ProductDetail/810-VLS3012HBX2R2M-N
DMP6350SQ-7 | SOT-23 | https://www.mouser.com/ProductDetail/621-DMP6350SQ-7
10K | 0603 | https://www.mouser.com/ProductDetail/71-CRCW0603-5.1K-E3
100K | 0603 | https://www.mouser.com/ProductDetail/603-RC0603FR-07100KL
15K | 0603 | https://www.mouser.com/ProductDetail/Bourns/CR0603-FX-1502ELF
5.6K | 0603 | https://www.mouser.com/ProductDetail/71-CRCW0603-5.6K-E3
100 | 0603 | https://www.mouser.com/ProductDetail/603-RC0603FR-07100RL
150 | 0603 | https://www.mouser.com/ProductDetail/603-RT0603FRE13150RL
430K | 0603 | https://www.mouser.com/ProductDetail/603-RC0603FR-13430KL
20K | 0603 | https://www.mouser.com/ProductDetail/603-RC0603FR-0720KL
47K | 0603 | https://www.mouser.com/ProductDetail/603-RC0603FR-0747KL
1.5M | 0603 | https://www.mouser.com/ProductDetail/71-CRCW0603-1.5M-E3
200K | 0603 | https://www.mouser.com/ProductDetail/603-RC0603FR-07200KL
3.3K | 0603 | https://www.mouser.com/ProductDetail/71-CRCW0603-3.3K-E3
49.9K | 0603 | https://www.mouser.com/ProductDetail/71-CRCW0603-49.9K-E3
2.2K | 0603 | https://www.mouser.com/ProductDetail/71-CRCW0603-2.2K-E3
5.1K | 0603 | https://www.mouser.com/ProductDetail/71-CRCW0603-5.1K-E3
1K | 0603 | https://www.mouser.com/ProductDetail/652-CR0603FX-1001ELF
270x4 | 1206 | https://www.mouser.com/ProductDetail/603-TC164-JR-07270RL
SKRTLAE010 | SW_SKRTLAE010 | https://www.mouser.com/ProductDetail/688-SKRTLA
CMS-151103-088SP | - | https://www.mouser.com/ProductDetail/490-CMS-151103-088SP
SKRRAAE010 | - | https://www.mouser.com/ProductDetail/688-SKRRAA
CGB CPU | -
MAX16054AZT+T | SOT-23-6 | https://www.mouser.com/ProductDetail/700-MAX16054AZTT
CGB RAM | -
BQ24072TRGTR | VQFN-16 | https://www.mouser.com/ProductDetail/595-BQ24072TRGTR
TPS61202DSC | WSON-10 | https://www.mouser.com/ProductDetail/595-TPS61202DSCR
LM4875MM_NOPB | VSSOP-8 | https://www.mouser.com/ProductDetail/926-LM4875MM-NOPB
MCP1700T-3302E/TT | SOT-23 | https://www.mouser.com/ProductDetail/579-MCP1700T3302E-TT
TLV803EB33VDBZR | SOT-23 | https://www.mouser.com/ProductDetail/595-TLV803EB33VDBZR
TLV3201AIDBVR | SOT-23-5 | https://www.mouser.com/ProductDetail/595-TLV3201AIDBVR
RK08H113003Q | RK08H113003Q | https://www.mouser.com/ProductDetail/688-RK08H113003Q
8.388608MHz | -
8.388608MHz | 5x7Crystal | https://www.aliexpress.us/item/3256805403138830.html
OWS-111535LA-8H | - | https://www.digikey.com/en/products/detail/ole-wolff-electronics-inc/OWS-111535LA-8H/17634911
74AHCT1G02DCKRG4 | SOT65P210X110-5N | https://www.mouser.com/ProductDetail/595-74AHCT1G02DCKRG4
MCP1319MT-33AE_OT | SOT-23-5 | https://www.mouser.com/ProductDetail/579-MCP1319MT33AE-OT
MCP1799T-3302H_TT | SOT-23 | https://www.mouser.com/ProductDetail/Microchip-Technology/MCP1799T-3302H-TT
732-CG838868MTJHPA | -
CMS-151135-078S-67 | - | https://www.digikey.com/en/products/detail/cui-devices/CMS-151135-078S-67/9561104
22pF | 0402 | https://www.mouser.com/ProductDetail/80-C0402C220G3HACTU
1uF | 0402 | https://www.mouser.com/ProductDetail/81-GRM155R61E105MA2D
2.2uF | 0402 | https://www.mouser.com/ProductDetail/81-GRM155R61E225ME1D
0.22uF | 0402 | https://www.mouser.com/ProductDetail/581-0402YC224KAT2A
100pF | 0402 | https://www.mouser.com/ProductDetail/77-VJ0402Y101MXAPBC
100nF | 0402 | https://www.mouser.com/ProductDetail/80-C0402C104M4R
FH33-28S-0.5SH_10_ | FH3328S05SH10 | https://www.mouser.com/ProductDetail/798-FH3328S0.5SH10
78171-0002 | 78171-0002 | https://www.mouser.com/ProductDetail/538-78171-0002
NTS4409NT1G | SOT65P220X100-3N | https://www.mouser.com/ProductDetail/863-NTS4409NT1G
10K | 0402 | https://www.mouser.com/ProductDetail/652-CR0402FX-1002GLF
100K | 0402 | https://www.mouser.com/ProductDetail/667-ERJ-U02J104X
100 | 0402 | https://www.mouser.com/ProductDetail/652-CR0402AJW-101GLF
15K | 0402 | https://www.mouser.com/ProductDetail/652-CR0402FX-1502GLF
3.3K | 0402 | https://www.mouser.com/ProductDetail/652-CR0402FX-3301GLF
430K | 0402 | https://www.mouser.com/ProductDetail/71-CRCW0402430KFKEDC
20K | 0402 | https://www.mouser.com/ProductDetail/652-CR0402FX-2002GLF
47K | 0402 | https://www.mouser.com/ProductDetail/652-CR0402FX-4702GLF
5.6K | 0402 | https://www.mouser.com/ProductDetail/652-CR0402JW-562GLF
200K | 0402 | https://www.mouser.com/ProductDetail/652-CR0402-JW-204GLF
49.9K | 0402 | https://www.mouser.com/ProductDetail/603-RP0402BRD0749K9L
5.1K | 0402 | https://www.mouser.com/ProductDetail/652-CR0402-JW-512GLF
1K | 0402 | https://www.mouser.com/ProductDetail/71-CRCW0402-1.0K-E3
Joy Con battery | - | https://www.ifixit.com/products/nintendo-switch-joy-con-controller-replacement-battery?variant=39372012322919
CMS-151135-18S-X8 | - | https://www.mouser.com/ProductDetail/CUI-Devices/CMS-151135-18S-X8?qs=9vOqFld9vZXAip8uBsd1PA%3D%3D

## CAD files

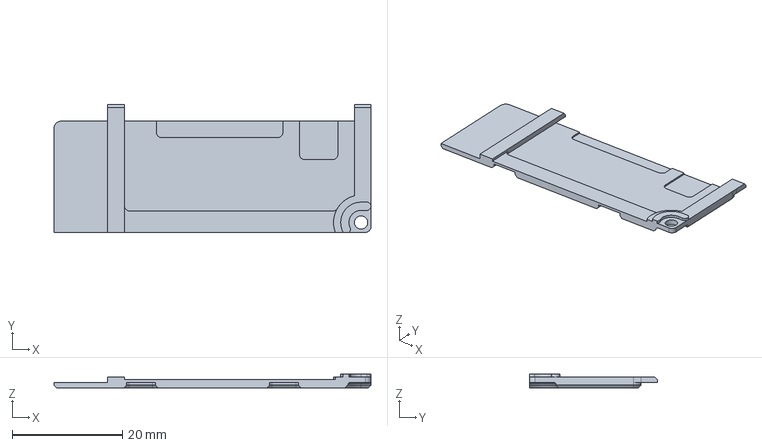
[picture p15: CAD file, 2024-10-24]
production_files/accessories/cart_shield/cartShield100624.step
57.6 x 23.2 x 2.54 mm

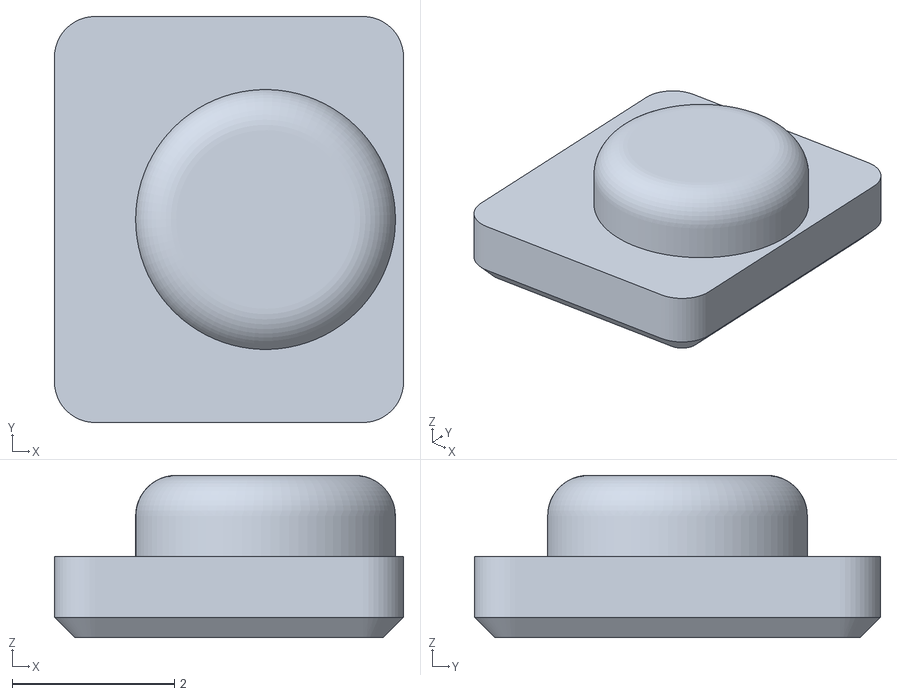
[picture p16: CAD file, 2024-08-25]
production_files/accessories/light_pipe/lightPipe_081224.stl
4.30 x 5.00 x 2.00

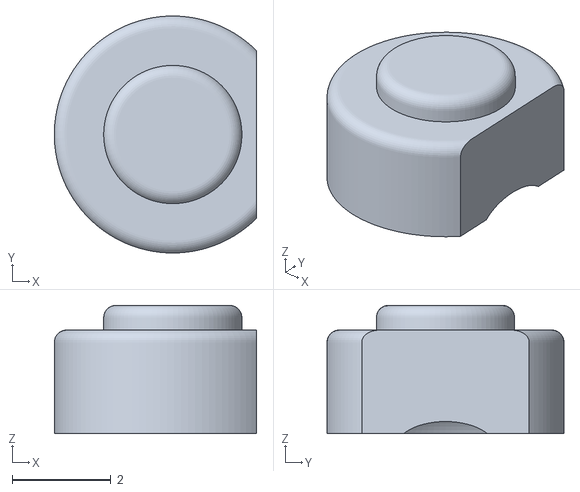
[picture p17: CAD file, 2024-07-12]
production_files/accessories/lightPipe.stl
4.10 x 4.80 x 2.60

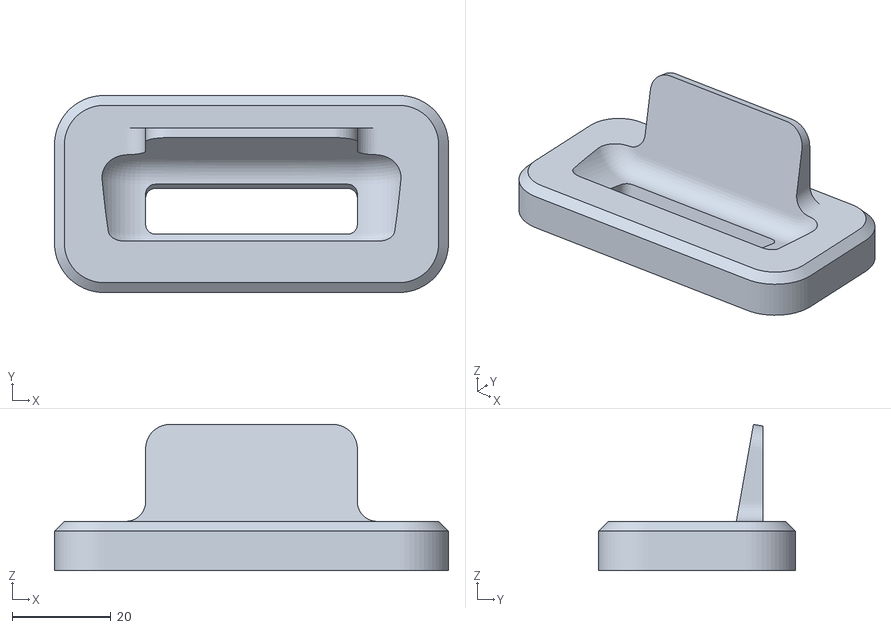
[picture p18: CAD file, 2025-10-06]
production_files/accessories/stand/tbc_stand.stl
80.0 x 40.0 x 29.7

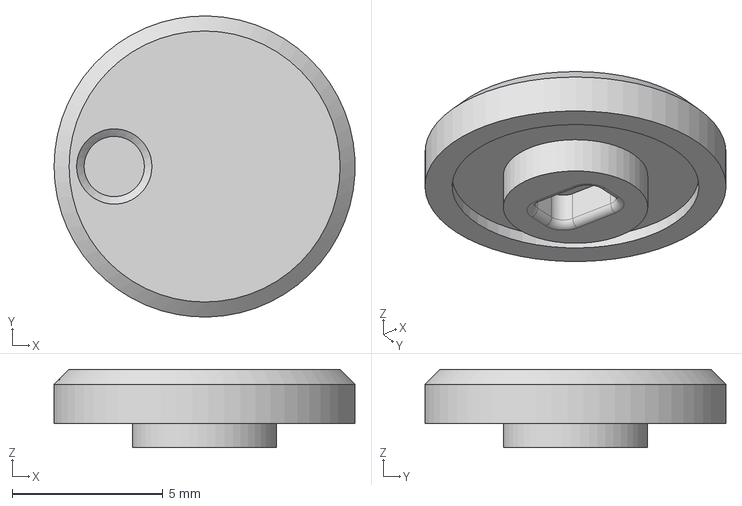
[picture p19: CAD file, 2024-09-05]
production_files/accessories/volume_wheel/ftbcVolumeWheel083124.step
9.99 x 10.00 x 2.60 mm

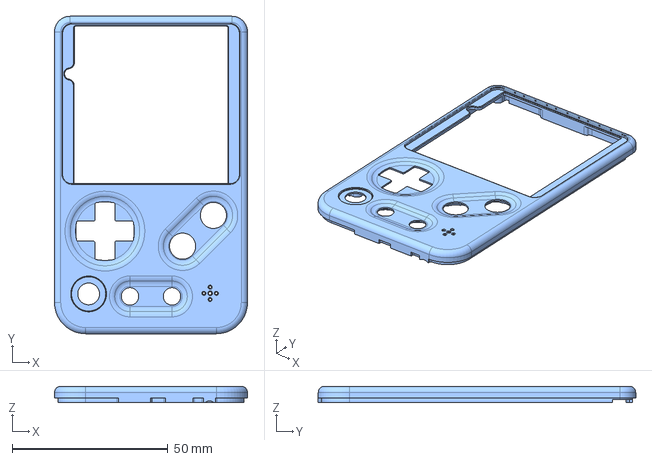
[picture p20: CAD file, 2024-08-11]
production_files/shell/071624/tbcFront071624.step
62.0 x 102.0 x 5.30 mm

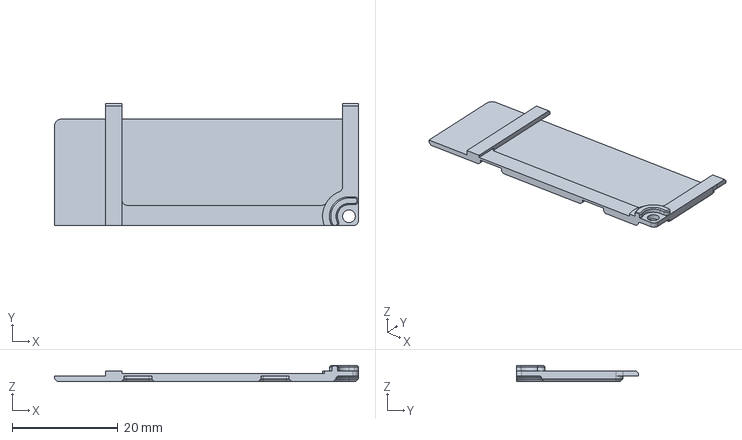
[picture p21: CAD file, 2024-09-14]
production_files/accessories/cart_shield/cartShield090124.step
57.6 x 23.2 x 3.04 mm

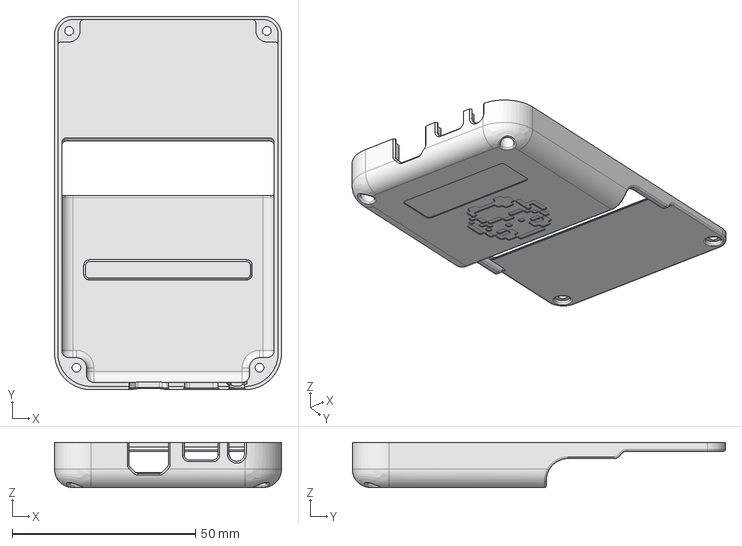
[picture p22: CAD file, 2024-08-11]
production_files/shell/071624/tbcBack071624.step
62.0 x 102.0 x 12.3 mm

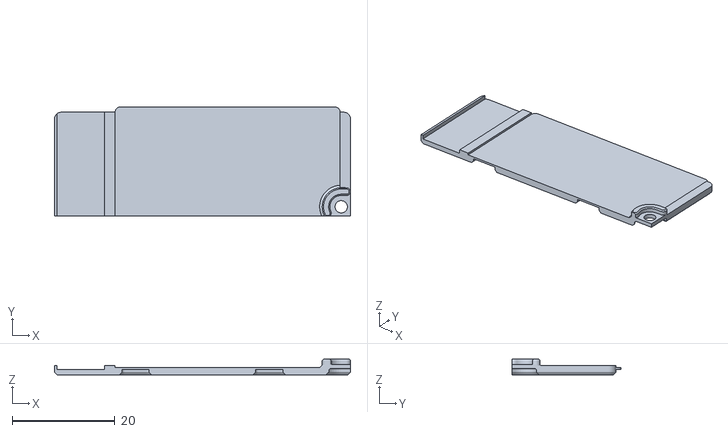
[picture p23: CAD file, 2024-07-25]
production_files/accessories/cart_shield/cartShield081124.stl
57.6 x 21.2 x 3.04

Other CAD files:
production_files/shell/tbcFront083124.step
production_files/accessories/volume_wheel/volumeWheel081124.stl
production_files/shell/tbcBack083124.step
production_files/accessories/cart_shield/cartShield082424.stl
production_files/accessories/volume_wheel/archive/volumeWheel081124.stl
production_files/accessories/cart_shield/archive/cartShield082424.stl

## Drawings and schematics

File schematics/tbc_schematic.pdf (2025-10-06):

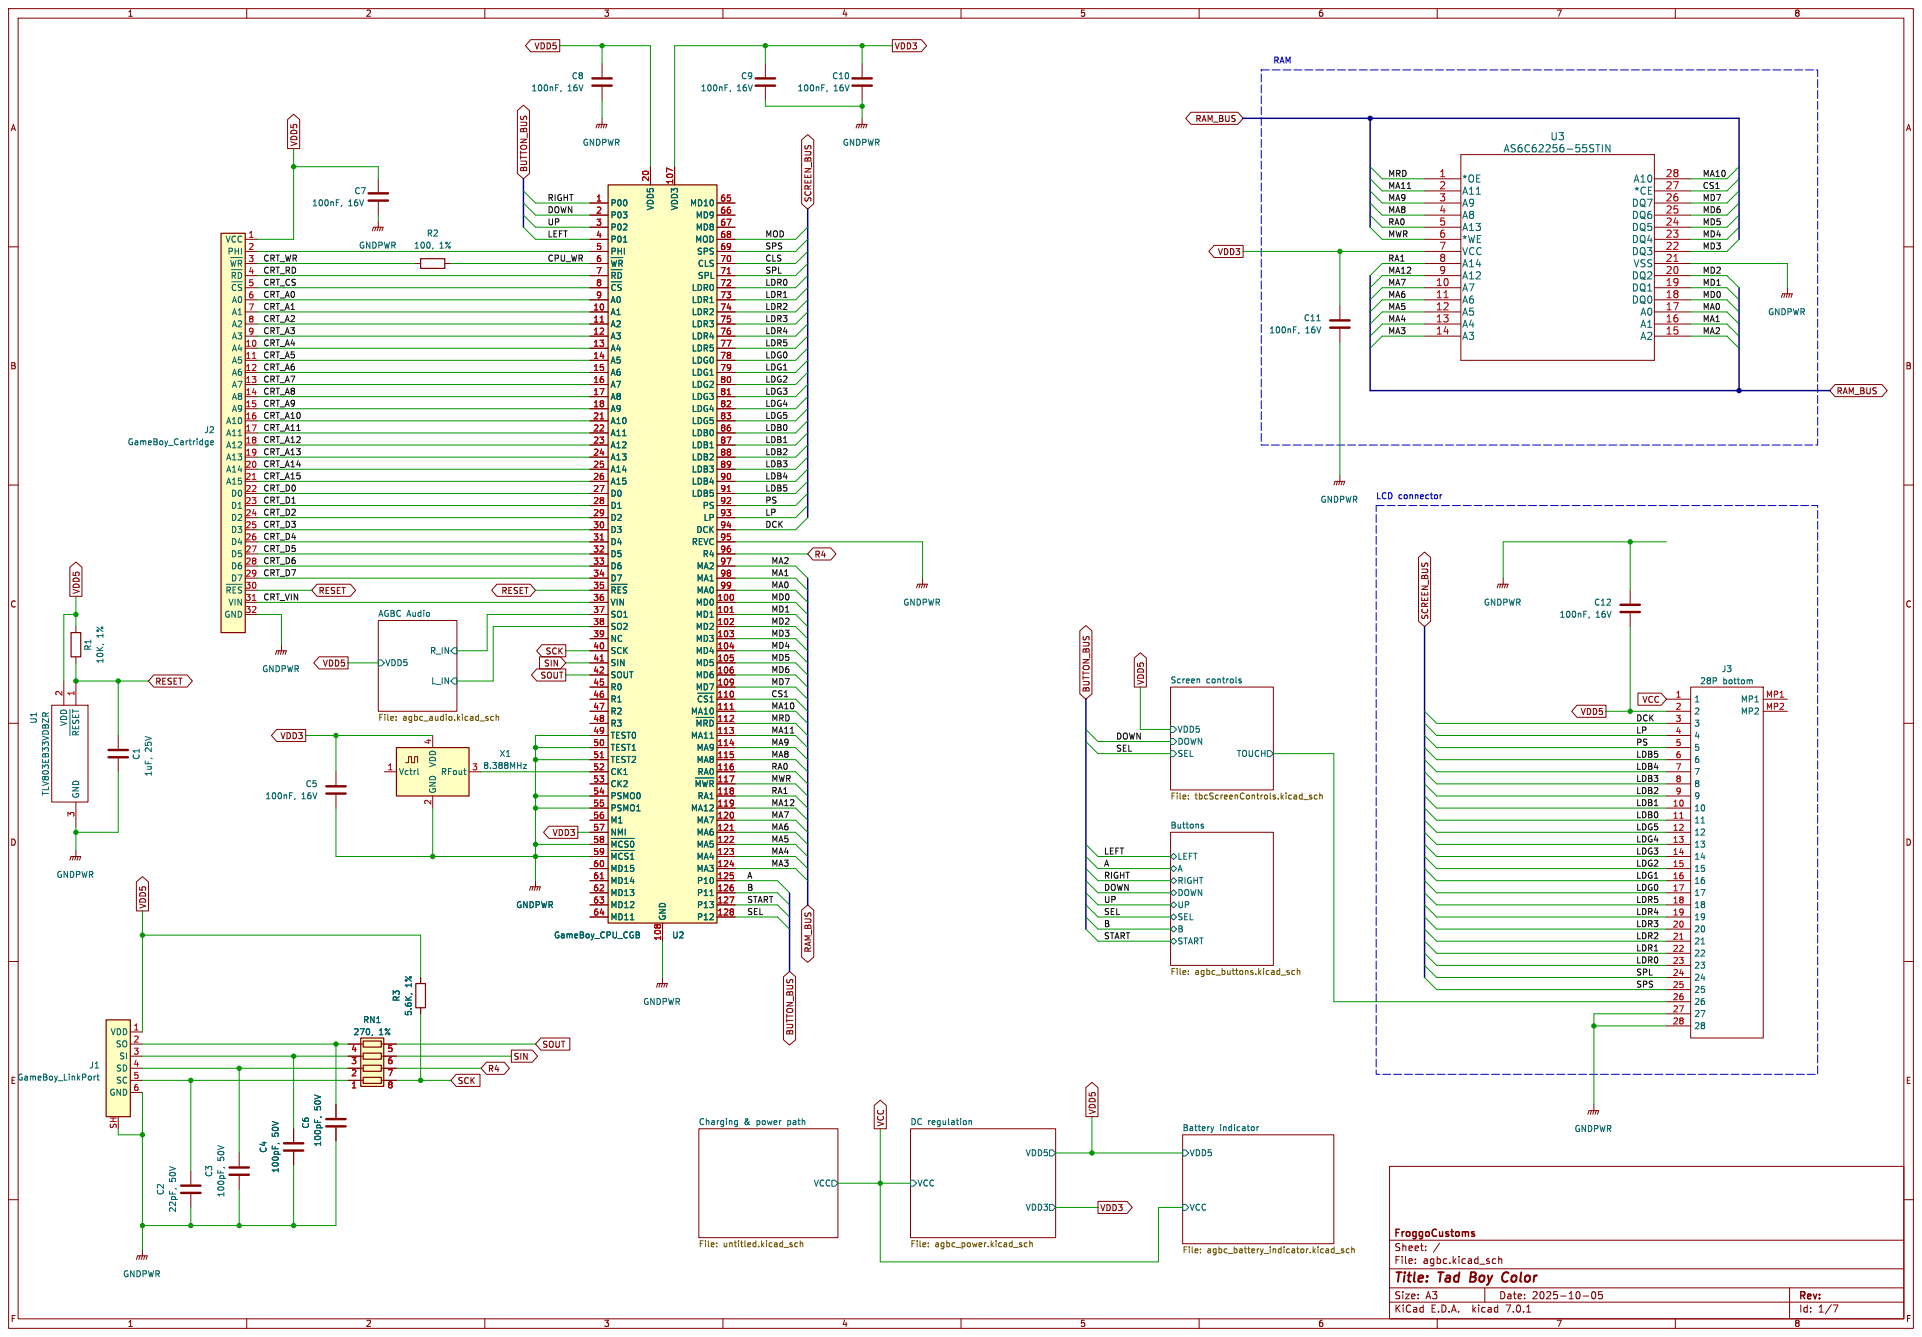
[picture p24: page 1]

VCC 1 A4 10 A5 11 A6 12 A7 13 A8 14 A9 15 A10 16 A11 17 A12 18 A13 19 PHI 2 A14 20 A15 21 D0 22 D1 23 D2 24 D3 25 D4 26 D5 27 D6 28 D7 29 ~{WR}3 ~{RES} 30 VIN 31 GND 32 ~{RD}4 ~{CS}5 A0 6 A1 7 A2 8 A3 9

Charging & power path File: untitled.kicad_sch

Id: 1/7 Title: Tad Boy Color File: agbc.kicad_sch Sheet: / FroggoCustoms VCC

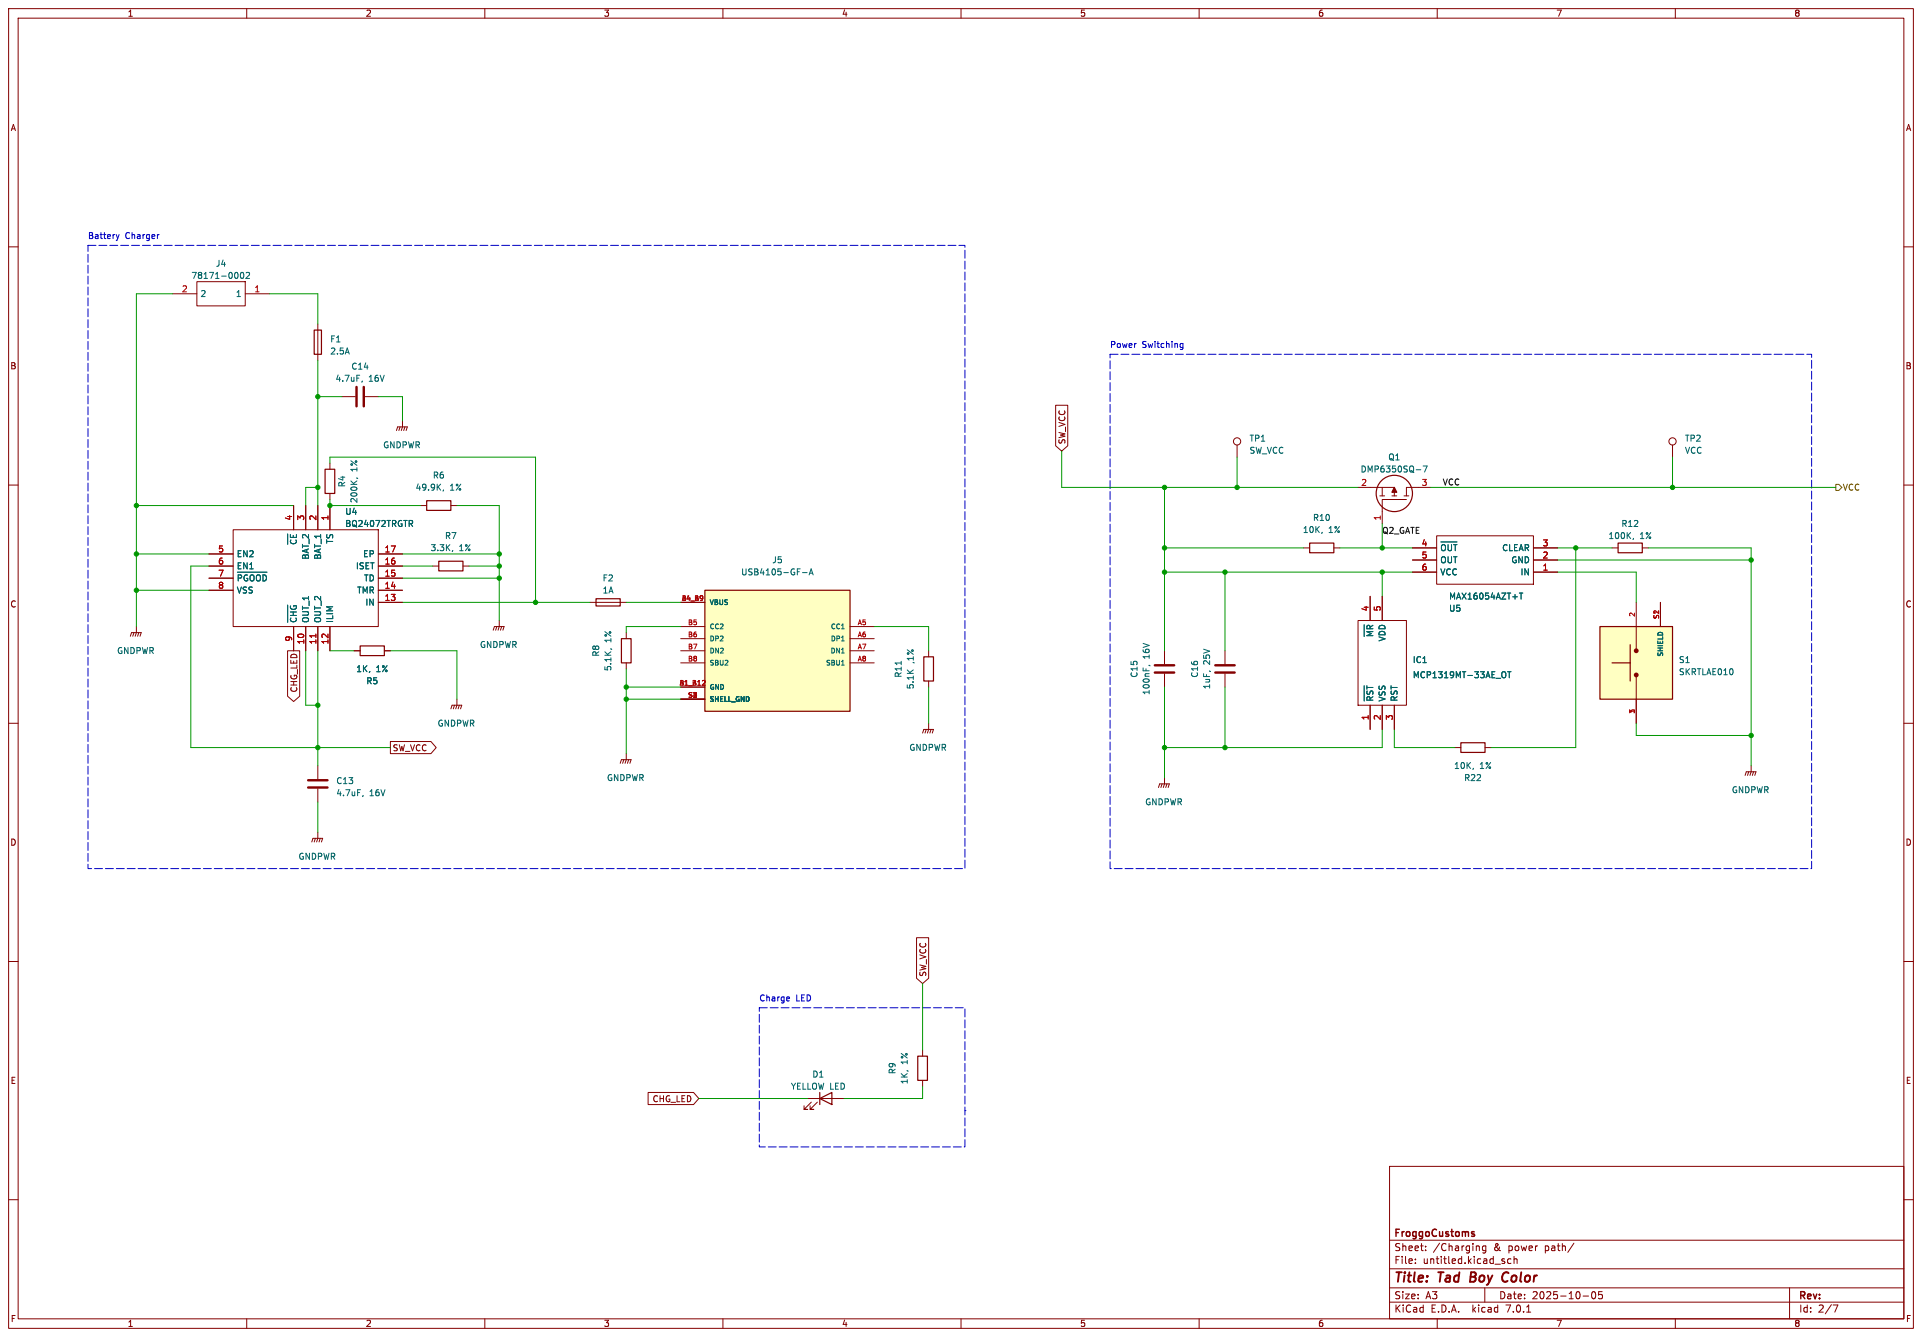
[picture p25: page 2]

3 ~{CE} 4 EN2 5 EN1 6 ~{PGOOD} 7 VSS 8 ~{CHG} 9 U4BQ24072TRGTR GNDPWR GNDPWR R8 5.1K, 1%

3 ~{CE} 4 EN2 5 EN1 6 ~{PGOOD} 7 VSS 8 ~{CHG} 9 R5

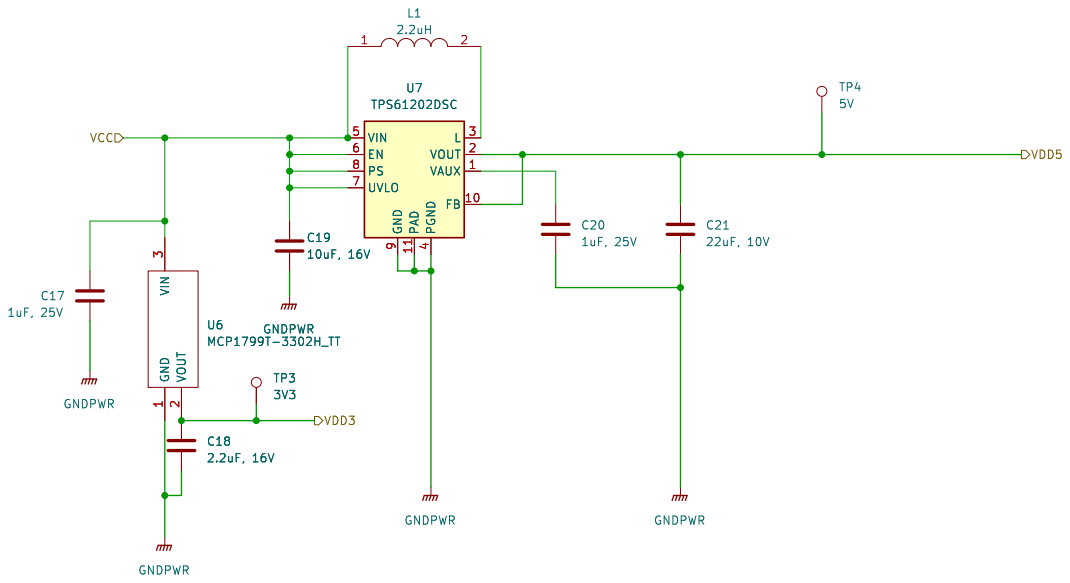
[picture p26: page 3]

4 VIN 5 EN 6 UVLO 7 PS 8 GND

FroggoCustoms
Id: 3/7 Title: Tad Boy Color File: agbc_power.kicad_sch Sheet: /DC regulation/

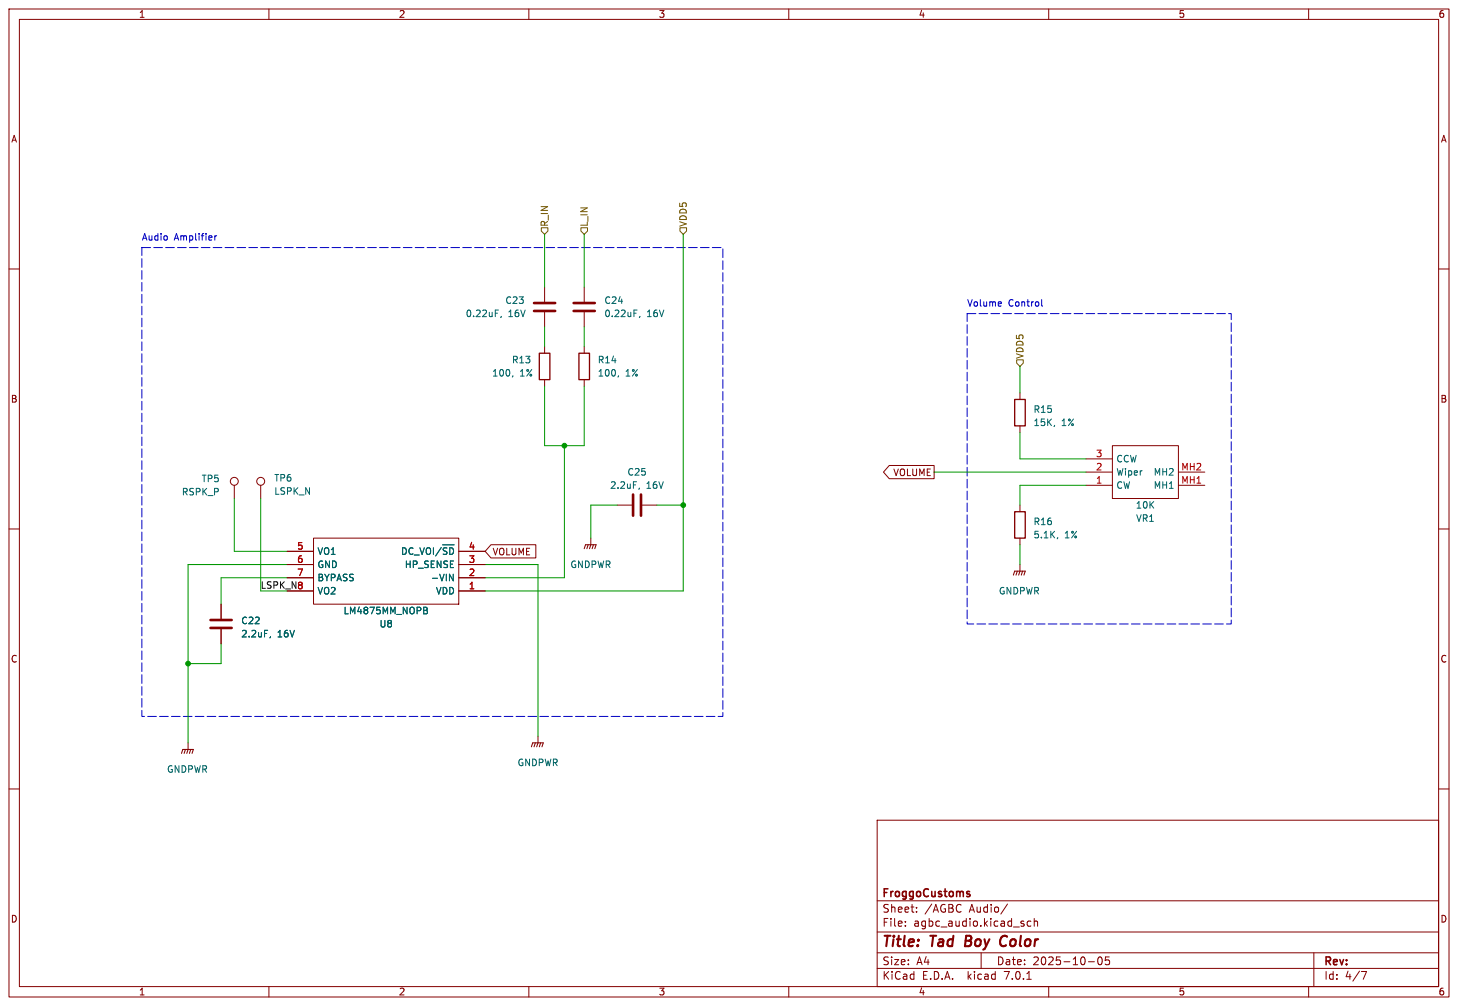
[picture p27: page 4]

Id: 4/7 Title: Tad Boy Color File: agbc_audio.kicad_sch Sheet: /AGBC Audio/ FroggoCustoms

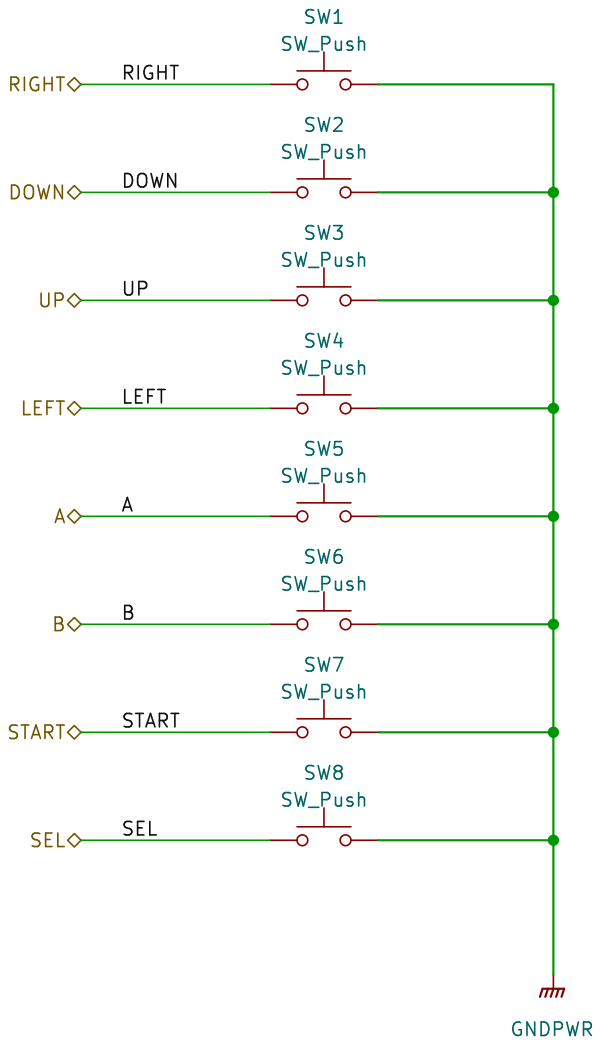
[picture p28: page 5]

LEFT RIGHT DOWN BA

Id: 5/7 Title: Tad Boy Color File: agbc_buttons.kicad_sch Sheet: /Buttons/ FroggoCustoms

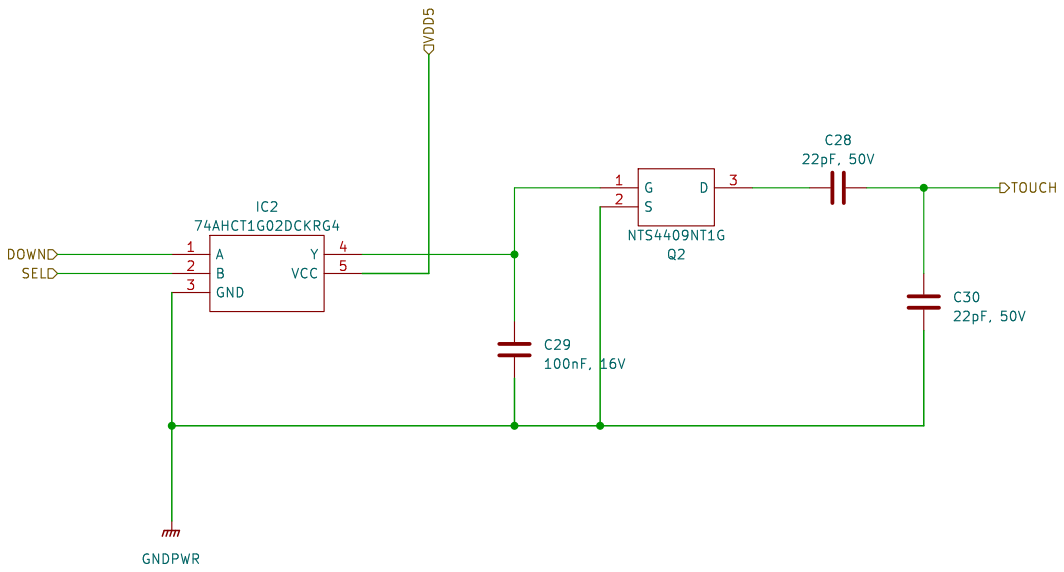
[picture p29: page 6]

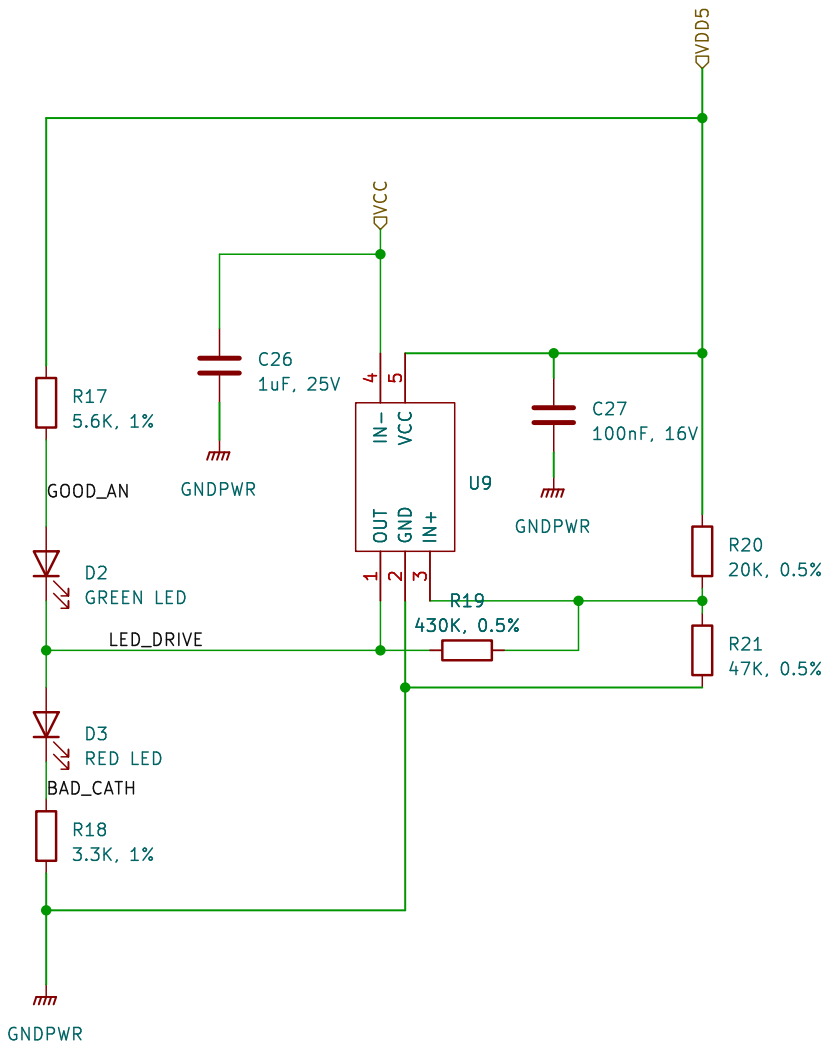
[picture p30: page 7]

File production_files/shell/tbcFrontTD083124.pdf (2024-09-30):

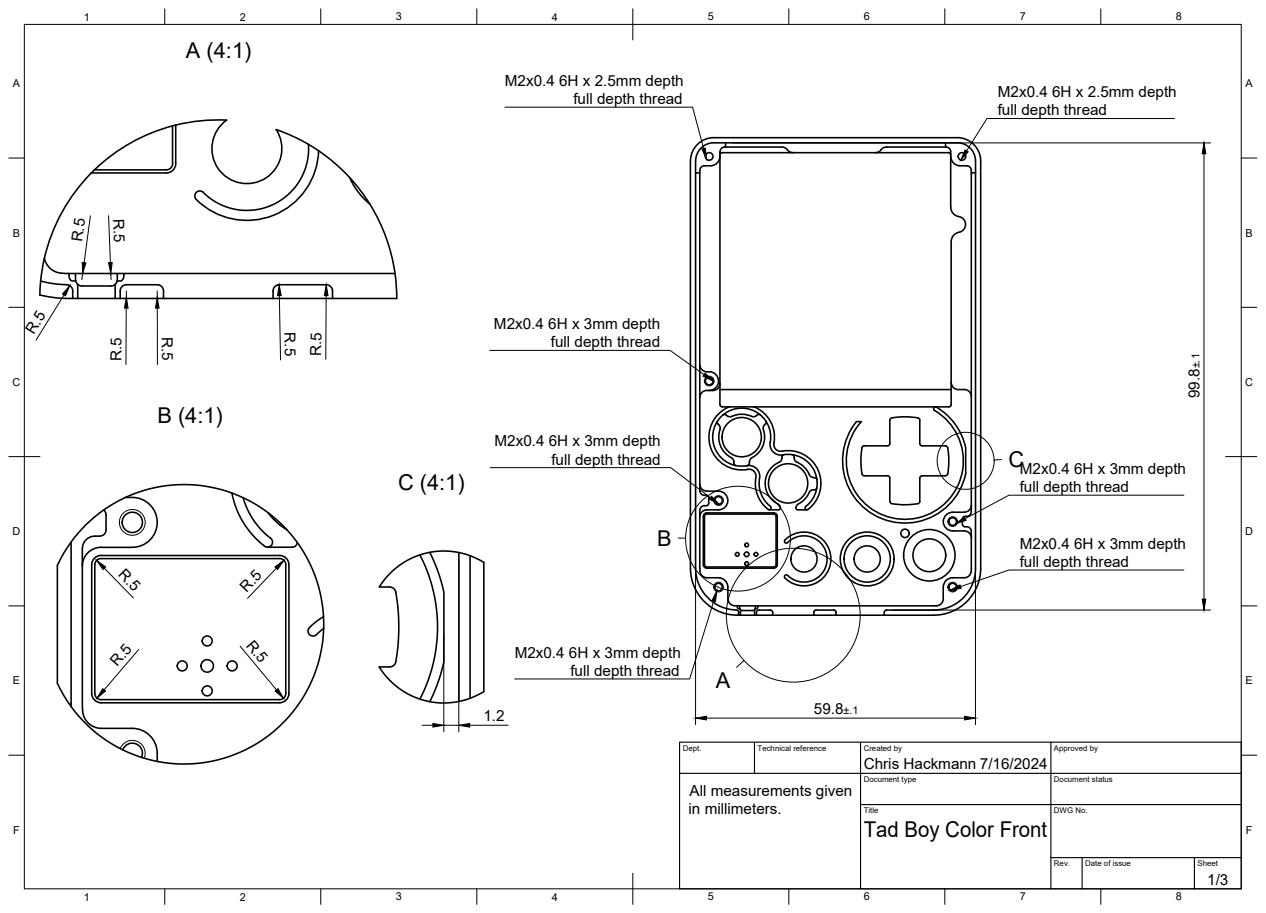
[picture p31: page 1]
Title; DWG No.; Rev.; Date of issue; Sheet; M2x0.4 6H x 2.5mm depth; full depth thread; M2x0.4 6H x 3mm depth; M2x0.4 6H x 3mm depth full depth thread; in millimeters.

full depth thread

M2x0.4 6H x 3mm depth

Dept. | Technical reference | Created by Chris Hackmann 7/16/2024 | Approved by

Document type | Document status

All measurements given

Tad Boy Color Front

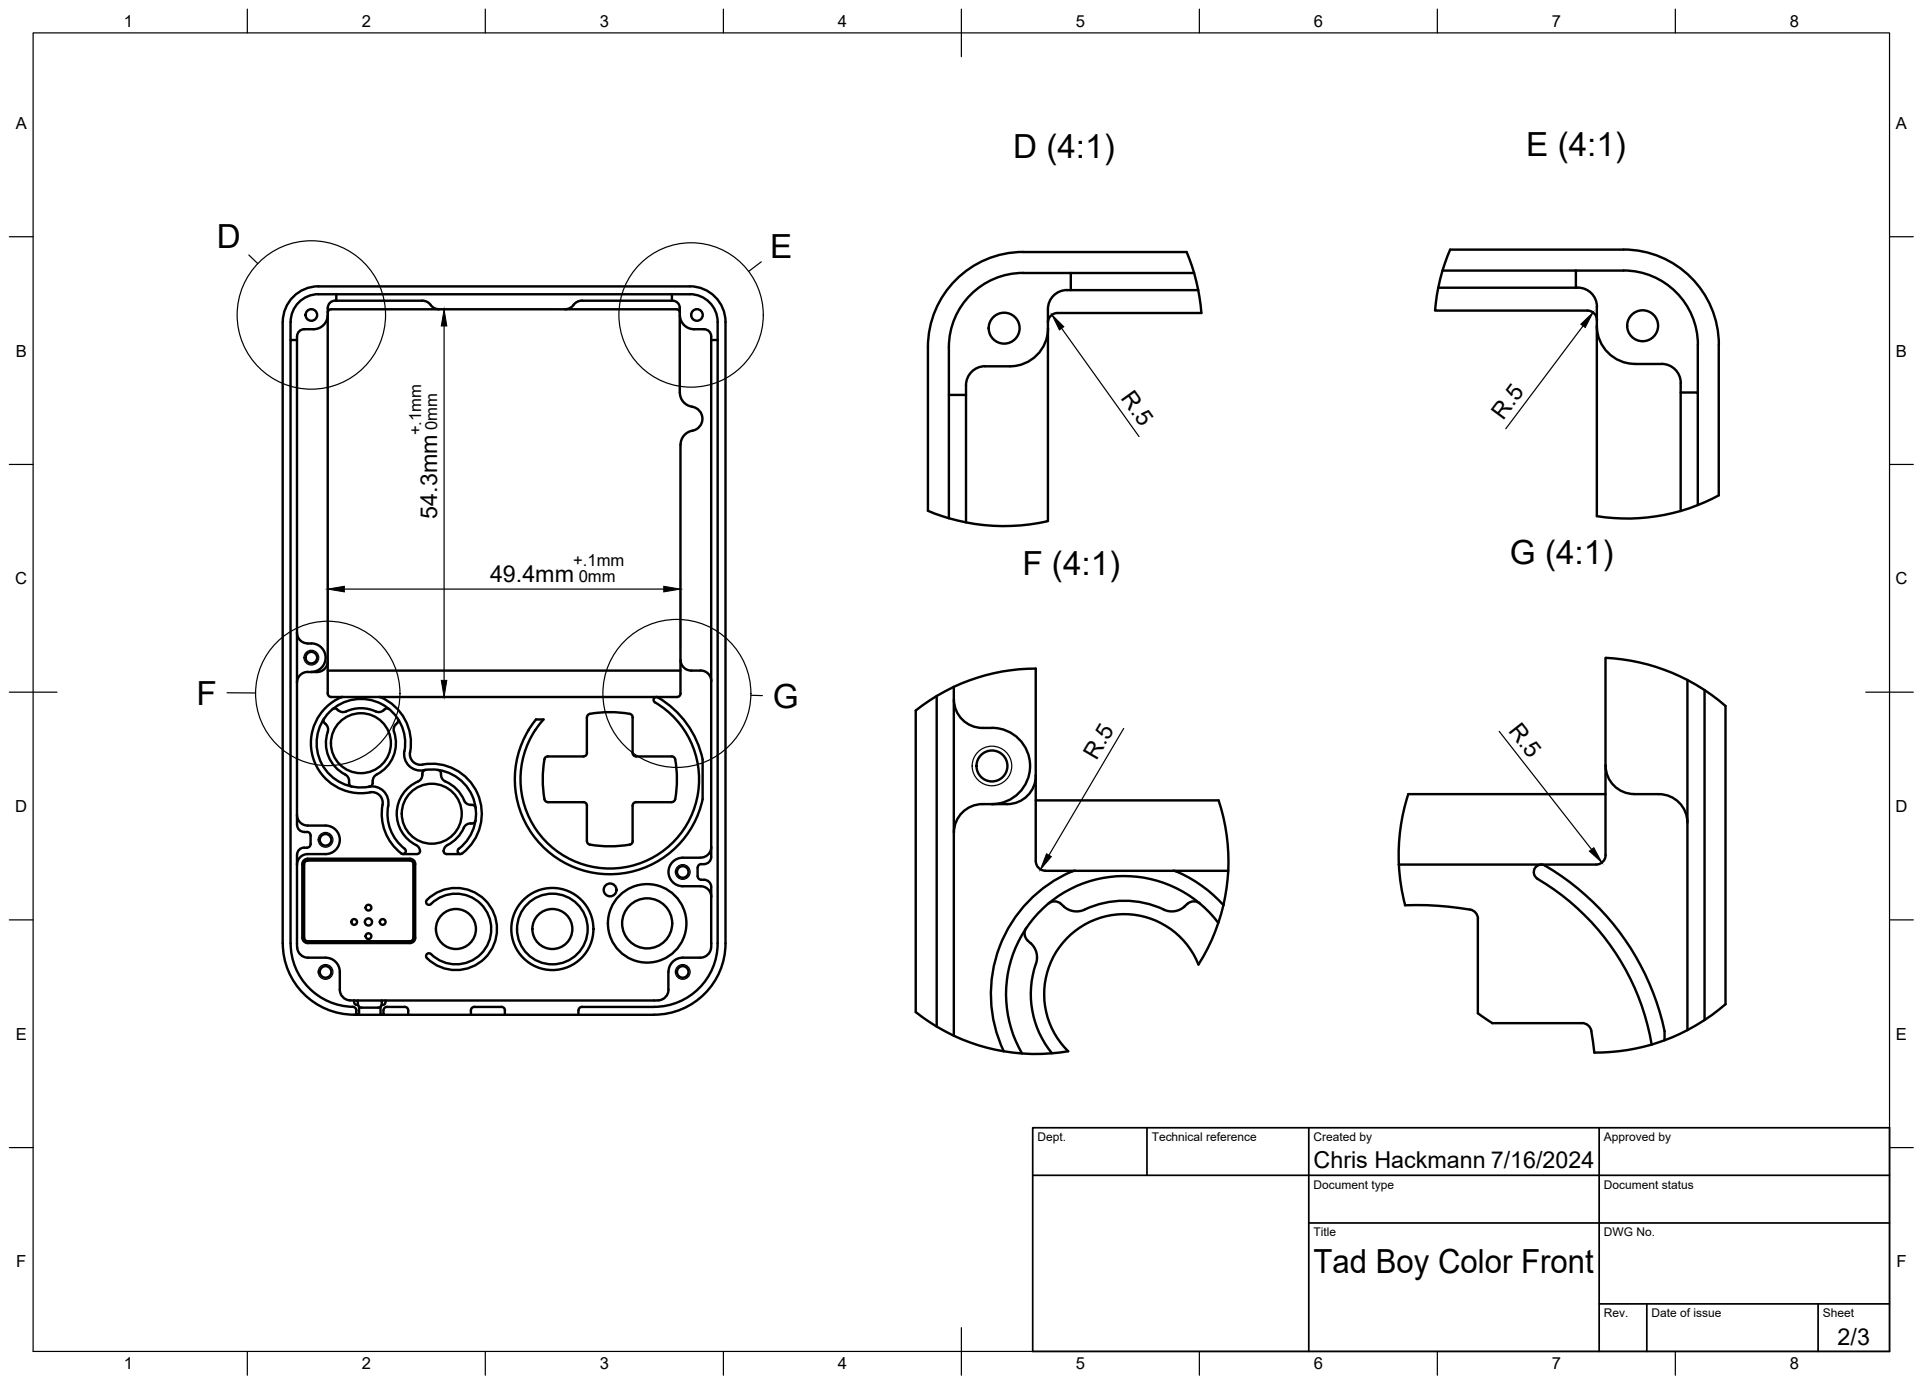
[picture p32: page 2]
Title; DWG No.

Dept. | Technical reference | Created by Chris Hackmann 7/16/2024 | Approved by

Document type | Document status

Tad Boy Color Front

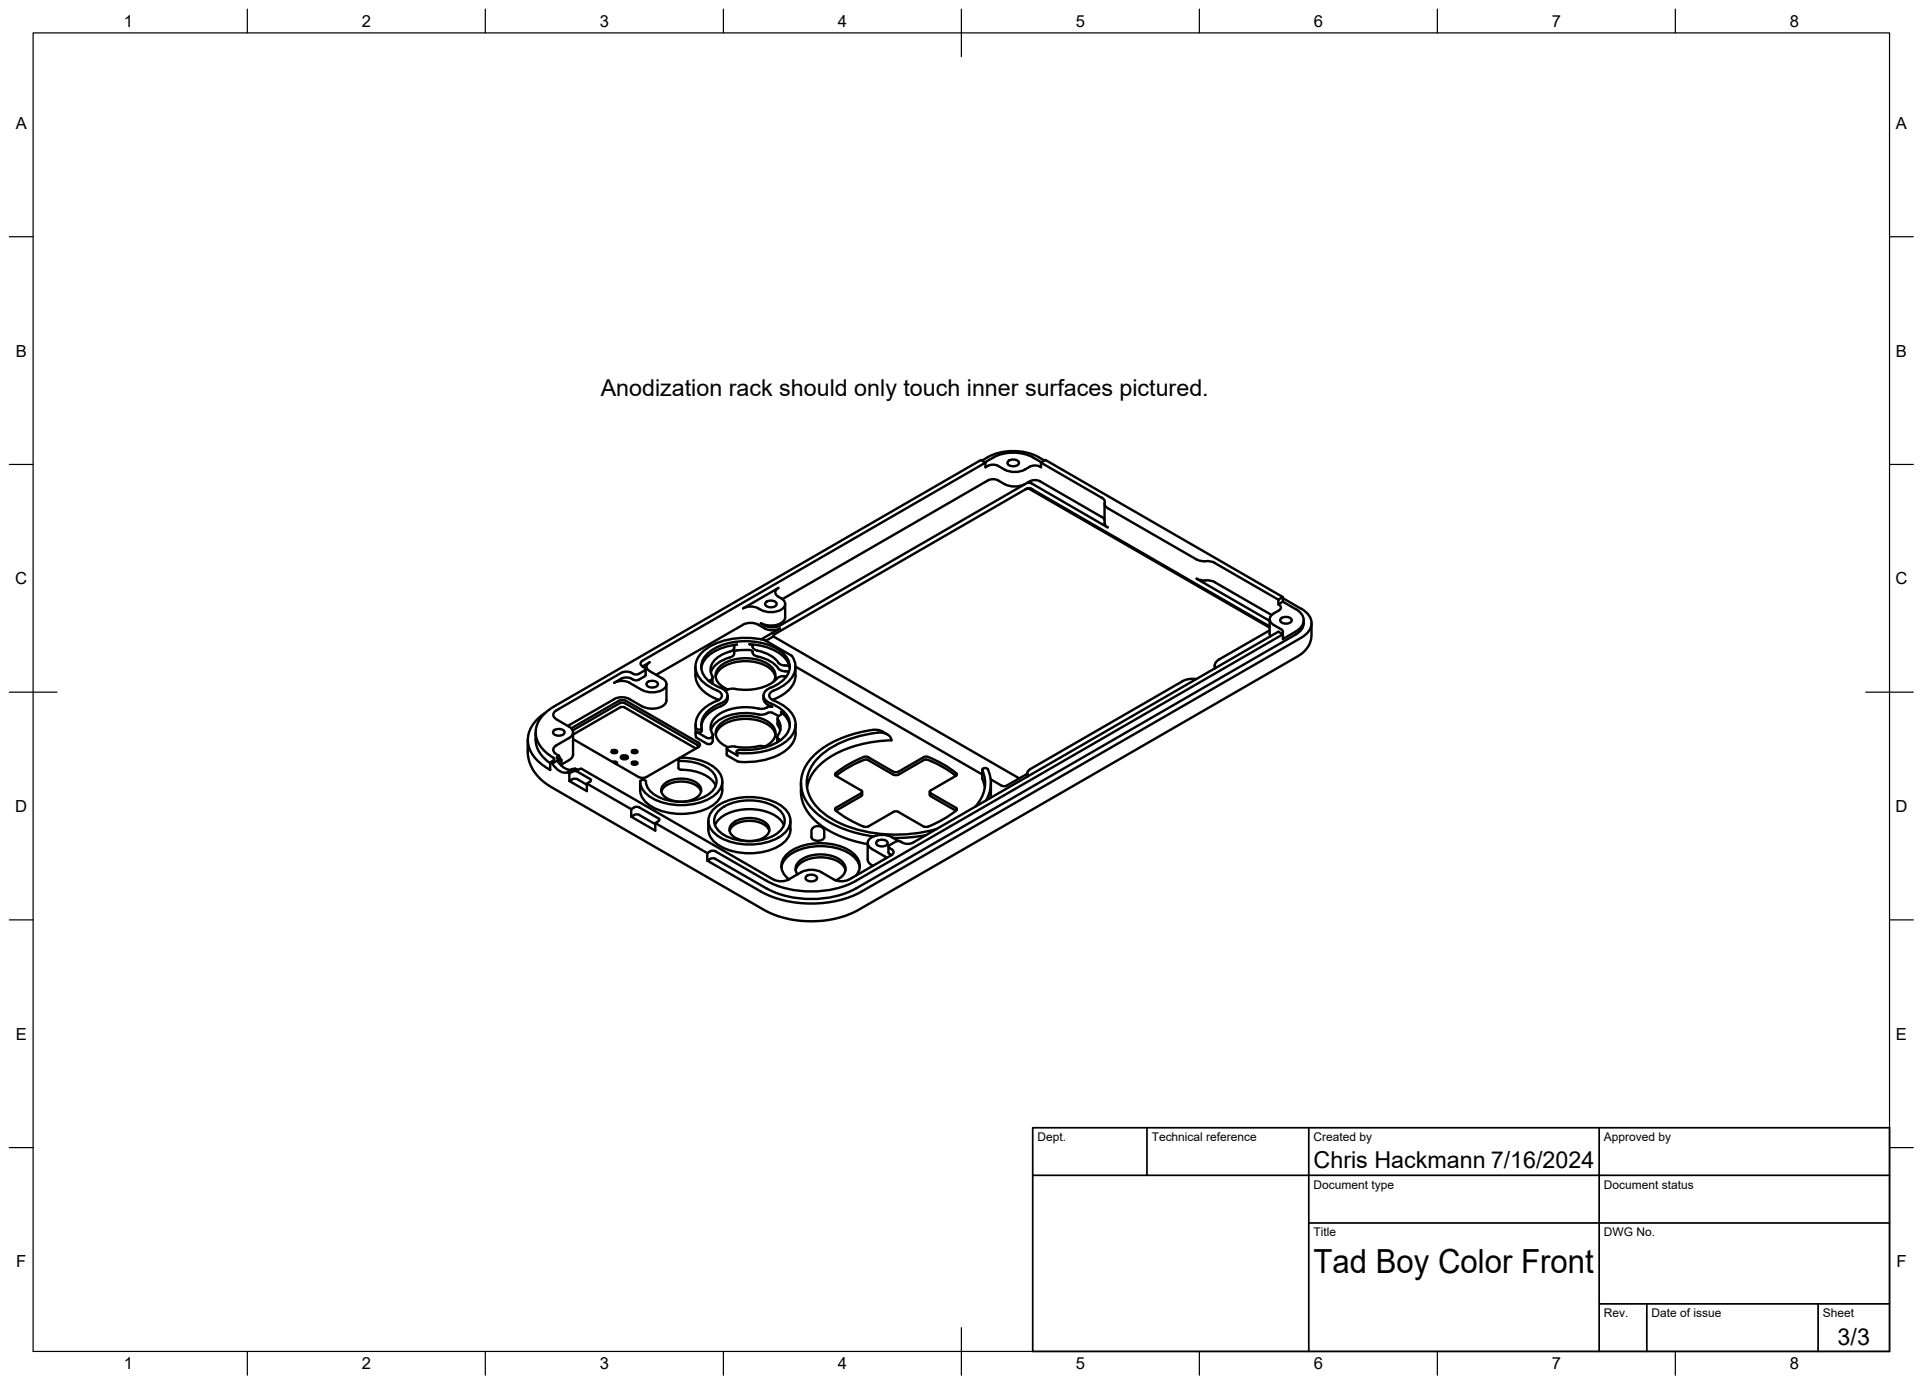
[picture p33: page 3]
Title; DWG No.

Anodization rack should only touch inner surfaces pictured.

Dept. | Technical reference | Created by Chris Hackmann 7/16/2024 | Approved by

Document type | Document status

Tad Boy Color Front

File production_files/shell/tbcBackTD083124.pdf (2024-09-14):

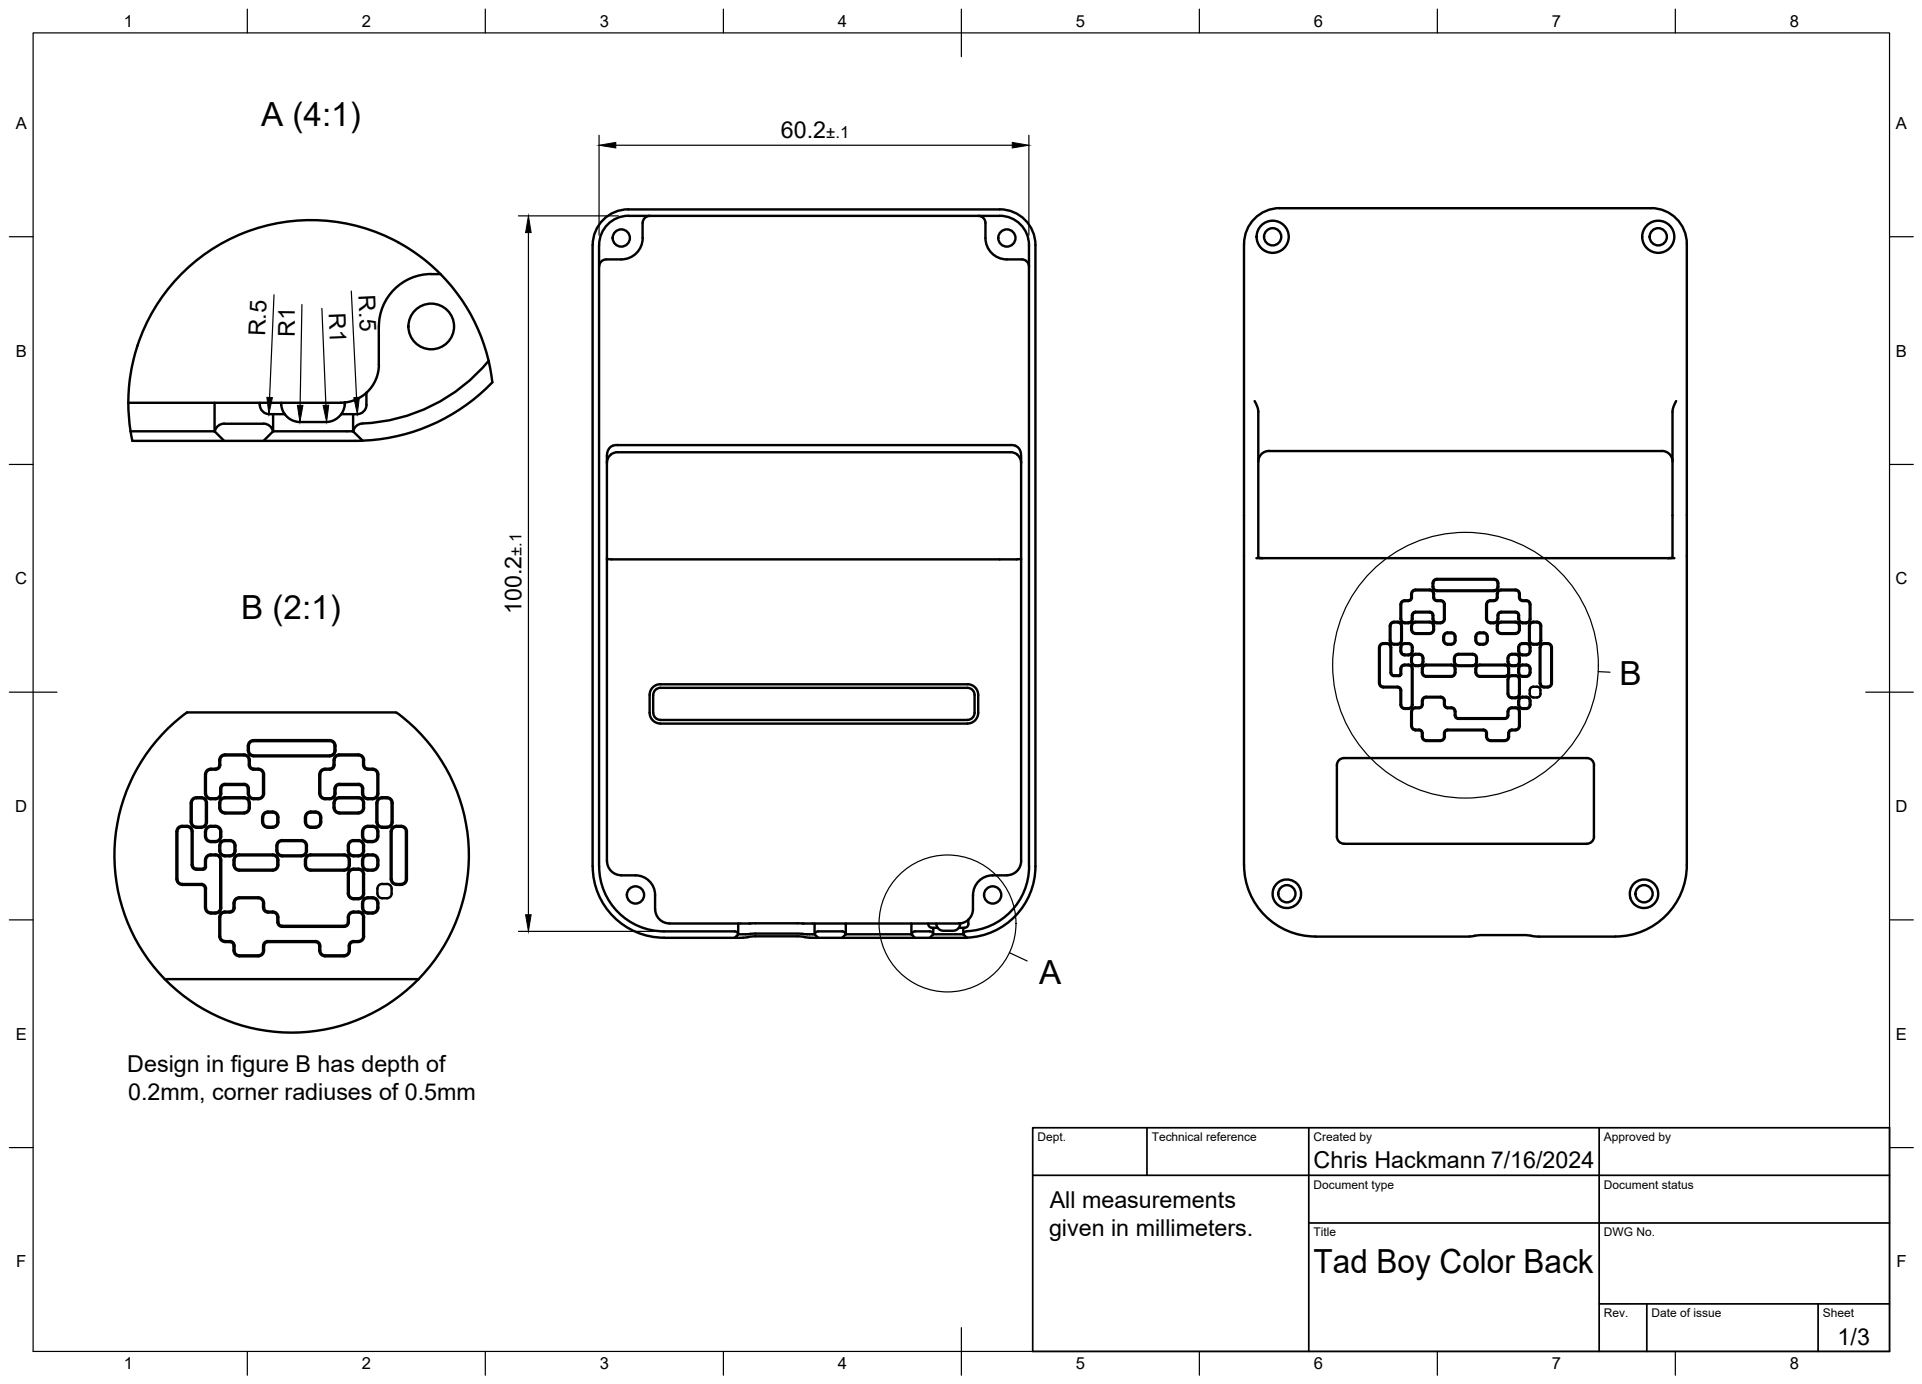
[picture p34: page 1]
Title; DWG No.; Rev.; Date of issue; Sheet; 0.2mm, corner radiuses of 0.5mm R.5

Design in figure B has depth of

Dept. | Technical reference | Created by Chris Hackmann 7/16/2024 | Approved by

Document type | Document status

All measurements
given in millimeters.

Tad Boy Color Back

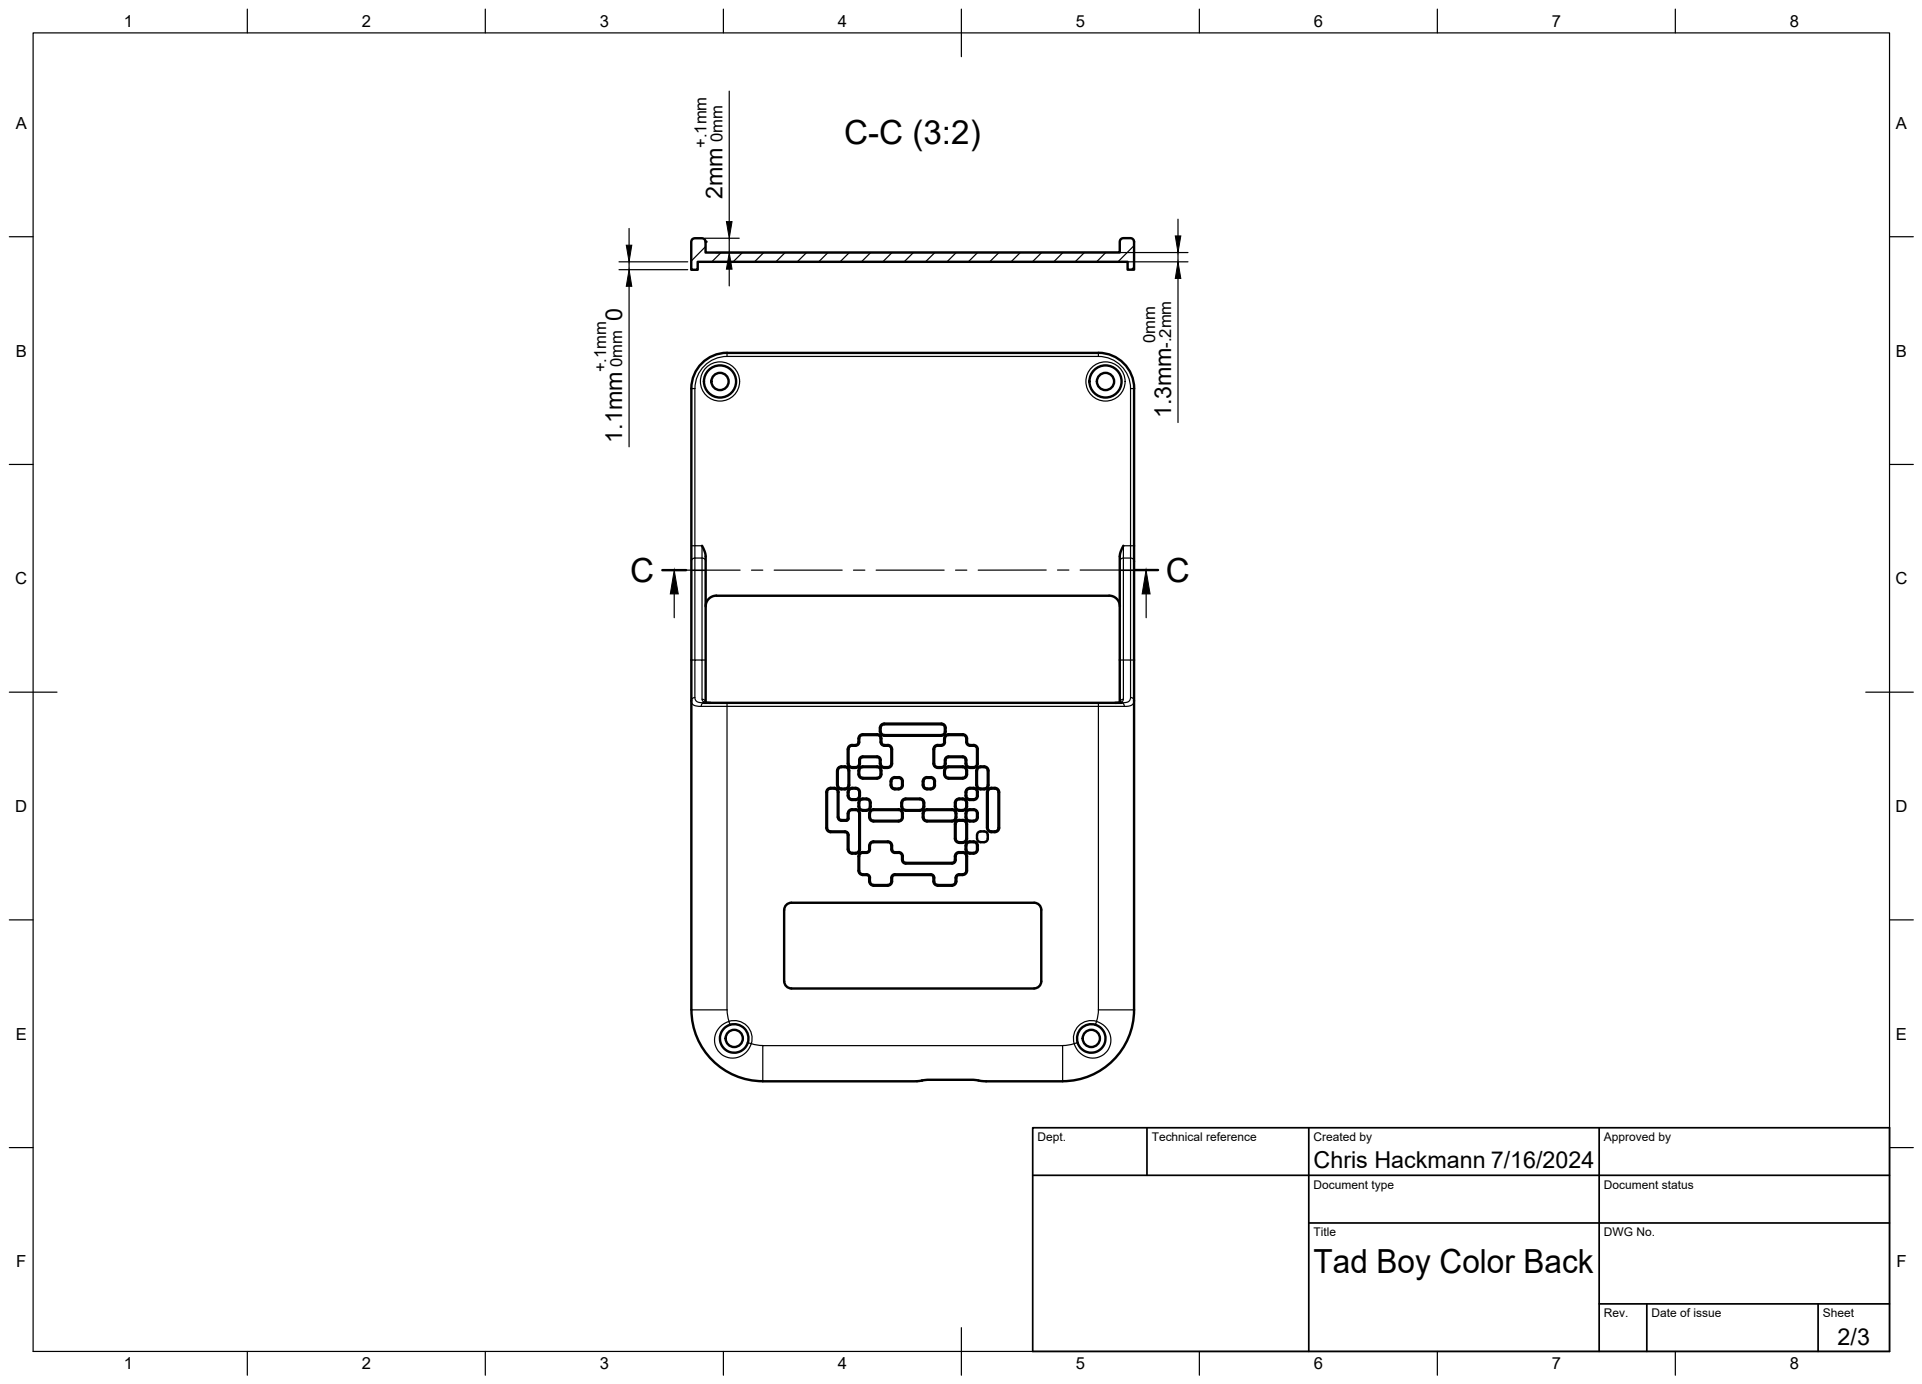
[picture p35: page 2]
Title; DWG No.

Dept. | Technical reference | Created by Chris Hackmann 7/16/2024 | Approved by

Document type | Document status

Tad Boy Color Back

Title; DWG No.

Anodizing rack should only touch inner surfaces pictured.

Dept. | Technical reference | Created by Chris Hackmann 7/16/2024 | Approved by

Document type | Document status

Tad Boy Color Back

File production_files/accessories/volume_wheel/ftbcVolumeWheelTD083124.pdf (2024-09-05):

Title; DWG No.; Rev.; Date of issue; Sheet; outside surface

1mm pitch diamond
knurling pattern around

Dept. | Technical reference | Created by Chris Hackmann 8/31/2024 | Approved by

Document type | Document status

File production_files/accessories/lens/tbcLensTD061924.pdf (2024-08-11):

8 BCDEF; ABCDEF Dept.; Technical reference; Created by; Approved by Document type; Document status Title; DWG No. Rev.; Date of issue; Sheet 6/15/2024; 1/1 Glass dimensions TBC Lens Front Chris Hackmann 56.60mm±0.10mm

R2.80mm Required glass specifications: - 0.8mm thickness - Rounded 2.5D edges - All corners have radius of 2.8mm Printing and double sided tape on side without rounded edges FRONT

8 BCDEF; ABCDEF Dept.; Technical reference; Created by; Approved by Document type; Document status Title; DWG No. Rev.; Date of issue; Sheet 6/15/2024; 1/1 TBC Lens Back Chris Hackmann NO TAPE IN THIS SQUARE Adhesive requirements: - Double sided tape dimensions on back(non rounded edges side) of glass. - Tape should be inset from glass edge by 0.5mm.

8 BCDEF; ABCDEF Dept.; Technical reference; Created by; Approved by Document type; Document status Title; DWG No. Rev.; Date of issue; Sheet 6/19/2024; 1/1 Chris Hackmann 56.6mm

15.84mm Preview of device lens fits into Silkscreen requirements: - Border around screen is BLACK - Border should extend to edge of glass - Corner radius of viewing window is 0.7mm in all corneers - Silkscreen is viewed from FRONT of device, pictured above - Circle cutout should be in TOP LEFT quadrant when device viewed from FRONT

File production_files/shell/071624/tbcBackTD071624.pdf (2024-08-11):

Title; DWG No.; Rev.; Date of issue; Sheet; 0.2mm, corner radiuses of 0.5mm R.5

Design in figure B has depth of

Dept. | Technical reference | Created by Chris Hackmann 7/16/2024 | Approved by

Document type | Document status

All measurements
given in millimeters.

Tad Boy Color Back

Title; DWG No.; Rev.; Date of issue; Sheet

Anodizing rack should only touch inner surfaces pictured.

Dept. | Technical reference | Created by Chris Hackmann 7/16/2024 | Approved by

Document type | Document status

Tad Boy Color Back

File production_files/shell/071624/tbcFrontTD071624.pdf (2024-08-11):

Title; DWG No.; Rev.; Date of issue; Sheet; M2x0.4 6H x 2.5mm depth; M2x0.4 6H x 3mm depth; M2x0.4 6H x 3mm depth full depth thread; in millimeters.

M2x0.4 6H x 2.5mm depth
full depth thread

M2x0.4 6H x 3mm depth

Dept. | Technical reference | Created by Chris Hackmann 7/16/2024 | Approved by

Document type | Document status

All measurements given

Tad Boy Color Front

Title; DWG No.

Dept. | Technical reference | Created by Chris Hackmann 7/16/2024 | Approved by

Document type | Document status

Tad Boy Color Front

Title; DWG No.

Anodization rack should only touch inner surfaces pictured.

Dept. | Technical reference | Created by Chris Hackmann 7/16/2024 | Approved by

Document type | Document status

Tad Boy Color Front

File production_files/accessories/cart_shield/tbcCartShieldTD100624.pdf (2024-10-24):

Title; DWG No.; Rev.; Date of issue; Sheet

Dept. | Technical reference | Created by Chris Hackmann 10/6/2024 | Approved by

Document type | Document status

TBC Cart Shield

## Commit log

2024-07-11 Added BOM excel file
    [bom.xlsx]
2024-07-12 Update README.md
    Added digikey cart to BOM section.
2024-07-12 Updated BOM
    [bom.xlsx]
2024-07-12 Added accessories
    [cartShield.stl, lightPipe.stl, tbcVolumeWheel.step]
2024-07-25 Updated cart shield
    [cartShield.stl]
2024-08-01 Add assembly images
2024-08-01 Update README.md
    Partial assembly instructions
2024-08-02 Update README.md
    Finished PCB assembly instructions.
2024-08-11 Added most production files
    [VolumeWheel-Old.step, cartShield.stl, lightPipe.stl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]
2024-08-11 New volume wheel; reformatted accessoreis folder
    [VolumeWheel-Old.step, cartShield081124.stl, lightPipe_deprecated.stl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]
2024-08-11 Fix link formatting for volume wheel
2024-08-11 Add PCB files
    [tbc01-B_Cu.gbr, tbc01-B_Mask.gbr, tbc01-B_Paste.gbr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]
2024-08-12 Add gerber files for the LCD adapter
    [tbc_la-B_Cu.gbr, tbc_la-B_Mask.gbr, tbc_la-B_Paste.gbr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]
2024-08-25 New light pipe; new cart shield
    [cartShield081124.stl, cartShield082424.stl, lightPipe_081224.stl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]
2024-09-05 Updated volume wheel files
    [ftbcVolumeWheel083124.step, volumeWheel081124.stl]
2024-09-14 Add updated shell; step file for cart shield
    [cartShield082424.stl, cartShield090124.step, tbcBack071624.step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]
2024-09-27 Added 02 board revision
    [tbc01-B_Cu.gbr, tbc01-B_Mask.gbr, tbc01-B_Paste.gbr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]
2024-09-27 Added PCBWay links.
2024-09-30 Fix missing thread info on front shell TD
2024-10-01 Another BOM update
    [bom.xlsx]
2024-10-05 Fix rotation on U4 in assembly file
    [tbc_02_centroid_pcbway.xls]
2025-01-04 Updated LCD adapater flex
    [tbc_la-B_Cu.gbr, tbc_la-B_Mask.gbr, tbc_la-B_Paste.gbr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]
2025-04-01 Adding Natalie's CPU E board
2025-10-06 Added schematic PDF
2025-10-06 Added STL for display stand
    [tbc_stand.stl]
2026-09-20 Add experimental front shell for plastics with room for threaded inserts
